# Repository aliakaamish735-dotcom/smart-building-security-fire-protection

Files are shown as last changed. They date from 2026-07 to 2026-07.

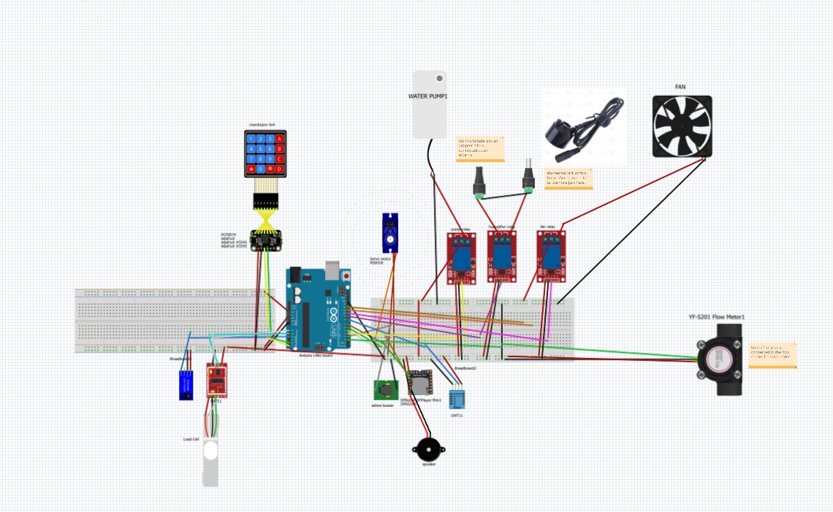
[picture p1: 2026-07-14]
docs/architecture_image.jpeg

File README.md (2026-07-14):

# Smart Building Security and Fire-Protection System

Welcome to the repository.

Smart Building Security and Fire-Protection System is an Arduino-based embedded sensing system integrating
optical, force, flow, temperature, and humidity sensors to provide intelligent entry security and automatic
fire detection and protection.

## Repository Contents

### 📁 `code/`

Contains the Arduino source code, firmware, diagnostics, and calibration
files.

### 📁 `data/`

Contains datasets, calibration files, CSV logs, and Excel workbooks.

### 📁 `docs/`

Contains the proposal, presentations, architecture diagrams, Fritzing
design, component documentation, and individual contributions.

### 📁 `report/`

Contains the final technical report.

### 📁 `video/`

Contains project demonstration and presentation video.

## Team Members

-   Ali Al Hadi Akaamish (6812)
-   Mustapha Hamdan (6947)
-   Nassim Amer (6939)
-   Makram Ghraizi (6723)

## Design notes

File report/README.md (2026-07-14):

# Security and Fire-Protection System

This folder contains the final technical report for the **Security and Fire-Protection System**, developed for the **Sensors & Instrumentation** course at the Lebanese University, Faculty of Engineering III.

## Main Report

- `security_and_fire_protection_systems_report.pdf`

The report presents the complete design, implementation, testing, data analysis, calibration framework, and evaluation of an Arduino-based smart sensing platform that combines building-entry security with automatic fire-protection functions.

## Project Team

1. **Ali Al Hadi Akaamish** — ID: 6812  
2. **Mustapha Hamdan** — ID: 6947  
3. **Nassim Amer** — ID: 6939  
4. **Makram Ghraizi** — ID: 6723  

**Instructor:** Dr. Mohamad Ahmad Aoude  
**Academic Year:** 2025–2026

## System Overview

The project is divided into two coordinated subsystems:

### Entry Security System

- TCRT5000 infrared optical sensor
- HX711 load-cell amplifier and load cell
- 4×4 keypad through a PCF8574 I²C expander
- SG90 servo-controlled door
- Security buzzer
- DFPlayer Mini voice guidance

A person is confirmed only when the optical sensor and entry-platform weight detection are both active. The user is then asked to enter a PIN. A correct PIN opens the door, while repeated incorrect attempts activate the security alarm.

### Fire-Protection System

- DHT11 temperature and humidity sensor
- YF-S201 water-flow sensor
- Mini water pump
- Ultrasonic humidifier
- Ventilation fan
- Warning LED
- Fire and blockage alarms
- DFPlayer Mini voice messages
- Three active-low relay modules

The fire-protection sequence monitors environmental conditions, detects high temperature, activates the pump, verifies water flow, operates the humidifier, controls ventilation, and records the system state.

## Sensor Modalities

The system integrates the five required sensor modalities:

- **Optical sensing:** TCRT5000
- **Force/weight sensing:** Load cell with HX711
- **Flow sensing:** YF-S201
- **Temperature sensing:** DHT11
- **Humidity sensing:** DHT11

## Report Contents

The report includes:

1. Introduction  
2. Problem Statement  
3. System Architecture  
4. Sensor Selection and Justification  
5. Hardware Design and Schematics  
6. Software Design and Firmware Architecture  
7. Calibration Procedures and Results  
8. Experimental Results and Data Analysis  
9. Measurement Uncertainty and Performance Analysis  
10. Engineering Constraints Discussion  
11. Conclusion and Future Work  
12. References  

It also includes appendices covering:

- Bill of Materials
- Verification and demonstration plan
- Proposal compliance matrix
- Calibration evidence and calculations
- Real-time acquisition and visualization
- Repository and submission checklist

## Data and Experimental Evidence

The report documents:

- 242 multi-sensor samples
- 113 system events
- Three acquisition sessions
- A longest continuous run of approximately 19.47 minutes
- Four recorded fire-response cycles
- Physical load-cell calibration trials
- Temperature, humidity, flow, event, and system-state visualizations
- Water-volume and timing calculations
- CSV-compatible timestamped data logging

## Hardware Documentation

The report contains the final Fritzing breadboard representation, interface mapping, power-domain explanation, relay connections, water-flow path, and complete Bill of Materials.

## Firmware Documentation

The firmware architecture includes:

- Continuous entry-security monitoring
- Five-second environmental acquisition and CSV logging
- Dual-sensor person confirmation
- Keypad PIN processing
- Servo-controlled door operation
- Fire-protection state machine
- Pump, humidifier, fan, LED, buzzer, and voice-message control
- Flow-based blockage detection
- Timestamped system-state records

## Recommended Repository Location

```text
report/
├── README.md
└── security_and_fire_protection_systems_report.pdf
```

## Purpose of This Document

This README provides a quick overview of the final report and helps reviewers understand the project scope, system structure, experimental work, and report organization before opening the complete PDF.

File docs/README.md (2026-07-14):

# Project Documentation

This folder contains the supporting documentation for the **Smart
Building Security and Fire-Protection System**.

## Files Included

### `Project_Team_Members.pdf`

Lists the project team members and their student IDs.

### `README_components.md`

Describes the hardware components, sensors, actuators, power supplies,
wiring accessories, and materials used in the project.

### `Smart_Laboratory_Security_Fire_Protection_Updated.pptx`

Final presentation used for the 10-minute technical presentation.

### `architecture_image.jpeg`

Illustrates the overall architecture of the system and the interaction
between the security and fire-protection subsystems.

### `questions&answers_ppt.pptx`

Contains the expected questions and prepared answers for the project
presentation and discussion.

### `sensors_architecture1.fzz`

Final Fritzing project containing the complete hardware wiring and
breadboard design.

### `sensors_project_proposal.pdf`

Original project proposal describing the objectives, requirements,
implementation plan, deliverables, and evaluation criteria.

## Purpose

These documents provide the technical background, hardware
documentation, presentation material, system architecture, and project
planning used throughout the design and implementation of the Smart
Building Security and Fire-Protection System.

## Folder Structure

``` text
docs/
├── README.md
├── Project_Team_Members.pdf
├── README_components.md
├── Smart_Laboratory_Security_Fire_Protection_Updated.pptx
├── architecture_image.jpeg
├── questions&answers_ppt.pptx
├── sensors_architecture1.fzz
└── sensors_project_proposal.pdf
```

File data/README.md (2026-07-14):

# Smart Building Security and Fire Protection — Project Data

This folder contains the complete dataset and analysis workbook for the **Smart Building Security and Fire Protection System**.

## Main Data File

- `whole_dataset_for_the_sensors_project(1).xlsx`

The Excel workbook is a standalone project database. It includes the original records, cleaned sensor data, event logs, calibration results, analysis-ready tables, charts, firmware constants, and a data dictionary.

## Important System Rule

The **HX711 load cell belongs only to the Entry Security System**.

It measures the weight applied to the entry platform and works together with the **TCRT5000 optical sensor** to confirm the presence of a person:

```text
Person detected = Optical detection AND Entry-platform weight detection
```

The load cell is **not used to measure the water tank** and is not interpreted as a fire-protection sensor.

## Workbook Contents

| Sheet | Description |
|---|---|
| `00_Cover` | Project description, fixed rules, cleaning decisions, and workbook summary |
| `01_Dashboard` | Main KPIs and charts for the report and presentation |
| `02_Parameters` | Firmware constants, thresholds, timings, and data-cleaning parameters |
| `03_Master_Data` | Organized master table containing sensor snapshots, system events, and calibration trials |
| `04_Clean_TimeSeries` | Clean, report-ready time-series sensor data |
| `05_Long_Observations` | Normalized sensor observations for calculations, filtering, and pivot tables |
| `06_Calibration` | Entry-platform load-cell calibration trials, equations, and results |
| `07_Event_Log` | Cleaned security, fire, and firmware event timeline |
| `08_Complete_Data_Archive` | Consolidated archive of all original project records |
| `09_Data_Dictionary` | Plain-English explanation of the important columns and variables |
| `10_Analysis_Data` | Analysis-ready records and calculated indicators |
| `11_Firmware_Calibration` | Calibration factors, equations, thresholds, and constants extracted from the firmware |
| `12_Nominal_References` | Reference values and comparison results |
| `13_Statistical_Calibration` | Simulated calibration points and before/after error calculations for modalities without complete measured calibration evidence |

## Dataset Summary

The workbook currently contains:

- **680** complete archive rows
- **370** master records
- **242** clean sensor snapshots
- **1,210** long-format sensor observations
- **113** cleaned system events
- **15** measured load-cell calibration trials

## Recorded Variables

The dataset includes values and events related to:

- TCRT5000 optical detection
- HX711 entry-platform weight
- DHT11 temperature and humidity
- YF-S201 water-flow rate
- Keypad activity and PIN-entry results
- Servo-controlled door operation
- Pump, humidifier, and fan states
- Fire-detection and suppression states
- Security alarms, wrong attempts, and detected errors

PIN values are masked in the clean analysis sheets.

## Main Firmware Parameters

| Parameter | Value |
|---|---:|
| Fire-temperature threshold | 28 °C |
| Flow blockage threshold | 0.05 L/min |
| Pump run duration | 55 s |
| Humidifier run duration | 10 s |
| Keypad inactivity timeout | 15 s |
| Maximum wrong attempts | 3 |
| Door-open duration | 5 s |
| TCRT5000 optical threshold | 500 ADC |
| Entry-platform weight threshold | 10 g |
| Flow calibration factor | 7.5 pulses/s per L/min |
| Sensor logging interval | 5 s |

These values are documented in the workbook and should be checked against the final physical calibration before the final demonstration.

## Data-Cleaning Decisions

The workbook preserves the original raw data while also providing clearly labelled cleaned and analysis-ready values.

- Negative load-cell readings remain preserved; the entry-weight analysis uses their positive magnitude.
- DHT11 values equal to `-1` are treated as failed sensor reads.
- Temperature values outside `0–60 °C` are excluded from clean measurements.
- Humidity values outside `0–100 %RH` are excluded from clean measurements.
- Very high historical flow values remain preserved; a clearly labelled analysis divisor is applied only where required.
- Legacy person-detection events are flagged when they do not follow the corrected optical-and-weight rule.

## How to Use the Workbook

1. Open `00_Cover` to review the system rules and workbook map.
2. Use `01_Dashboard` for presentation-ready KPIs and charts.
3. Use `03_Master_Data` for the organized complete dataset.
4. Use `04_Clean_TimeSeries` for sensor trends and report charts.
5. Use `07_Event_Log` to review security and fire-system actions.
6. Use `06_Calibration` and `11_Firmware_Calibration` when discussing sensor calibration.
7. Use `09_Data_Dictionary` to understand each important column.

## Calibration Note

Measured three-point calibration evidence is currently complete for the **entry-platform load cell**. Some additional calibration tables are based on nominal references or simulated data and are clearly identified as such inside the workbook. They should not be presented as physical measurements.

## File Organization

```text
data/
├── whole_dataset_for_the_sensors_project(1).xlsx
└── README.md
```

No additional `raw`, `processed`, or `calibration` folders are required because these categories are already organized into separate sheets inside the Excel workbook.

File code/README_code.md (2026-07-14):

# Project Source Code

This folder contains the complete source code for the **Smart Building Security and Fire-Protection System**.

## Code Structure

- `arduino_firmware/` — Main integrated Arduino firmware, calibration files, algorithm documentation, CSV logger, and experimental log.
- `arduino_firmware_modular/` — Modular implementation with separate configuration, security, fire-protection, relay, and sensor-driver files.
- `arduino_diagnostics/` — Diagnostic and calibration firmware used to test the connected hardware.
- `Code with no text output/` — Firmware version prepared for the final demonstration without additional Serial text messages.

## Main Features

- TCRT5000 optical person detection
- HX711 load-cell measurement
- DHT11 temperature and humidity monitoring
- YF-S201 water-flow measurement
- 4×4 keypad authentication through PCF8574
- SG90 servo-controlled door
- DFPlayer Mini voice guidance
- Pump, humidifier, and fan control through relay modules
- Timestamped CSV output
- Calibration constants and EEPROM support
- Modular Arduino C/C++ architecture
- Python serial-to-CSV logging utility

## External Libraries and Credits

The firmware uses the following external and Arduino-provided libraries. Their original authors, source repositories, and licenses are credited below.

### Third-Party Libraries

| Library | Author / Maintainer | Purpose | Source | License |
|---|---|---|---|---|
| DHT Sensor Library | Adafruit Industries | Reads DHT11 temperature and humidity values | https://github.com/adafruit/DHT-sensor-library | MIT License |
| HX711 Arduino Library | Bogdan Necula and contributors | Interfaces the HX711 load-cell amplifier | https://github.com/bogde/HX711 | MIT License |
| DFRobotDFPlayerMini | DFRobot | Controls the DFPlayer Mini audio module | https://github.com/DFRobot/DFRobotDFPlayerMini | MIT License |
| ArduinoJson | Benoit Blanchon and contributors | JSON formatting and data handling in diagnostic/modular code | https://github.com/bblanchon/ArduinoJson | MIT License |
| pySerial | Chris Liechti and contributors | Reads Arduino Serial data in the Python CSV logger | https://github.com/pyserial/pyserial | BSD-3-Clause License |

### Arduino-Provided Libraries

| Library | Provider | Purpose | Source | License |
|---|---|---|---|---|
| Servo | Arduino | Controls the SG90 servo motor | https://github.com/arduino-libraries/Servo | LGPL-2.1-or-later |
| Wire | Arduino | Provides I²C communication for the PCF8574 keypad expander | https://github.com/arduino/ArduinoCore-avr | LGPL-2.1-or-later |
| EEPROM | Arduino | Stores calibration constants in non-volatile memory | https://github.com/arduino/ArduinoCore-avr | LGPL-2.1-or-later |
| SoftwareSerial | Arduino | Provides software-based serial communication for the DFPlayer Mini | https://github.com/arduino/ArduinoCore-avr | LGPL-2.1-or-later |

## Project-Written Files

The subsystem algorithms, configuration files, calibration constants, sensor wrappers, relay logic, diagnostic routines, and project documentation included in this folder were developed specifically for this project.

## Programming Languages

- Arduino C/C++
- Python

## Usage

1. Install the required Arduino libraries through the Arduino IDE Library Manager.
2. Open the required `.ino` file in the Arduino IDE.
3. Select **Arduino Uno** and the correct serial port.
4. Compile and upload the firmware.
5. Use the Serial Monitor or `serial_csv_logger.py` to record CSV-formatted sensor data.

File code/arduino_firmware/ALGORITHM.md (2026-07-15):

# Firmware Algorithm — Smart Building Security and Fire Protection System

This document describes the **logic** of the firmware in plain pseudocode,
independent of Arduino syntax. It's meant to sit alongside `README.md`
(wiring/setup) as the "how it thinks" reference for the report's
Algorithm / Firmware Logic section.

The system is fully standalone (no WiFi/network) and runs two
independent subsystems every loop iteration: **Entry Security** and
**Fire Protection**. A third, smaller routine (**Ambient Humidity Fan
Control**) runs alongside Fire Protection but does not interact with it.

All numeric constants referenced below (in CAPS) live in
`CalibrationConstants.h` — nothing here is hard-coded in the driver files.

---

## 1. Main Loop

```
LOOP forever:
    POLL entry security (proximity + weight pad + keypad)   // every iteration, never skipped
    UPDATE fire-event buzzer timer                          // non-blocking, every iteration

    IF (time since last sensor read) >= SENSOR_POST_INTERVAL:
        RUN one fire-protection state-machine step
        LOG a CSV data row (temp, humidity, pad weight, flow, proximity, fire stage, wrong attempts)
```

Entry security is polled on **every single loop iteration**, regardless
of what the fire-protection state machine is doing. This guarantees a
fire event, a running pump, or a running humidifier never blocks
someone from unlocking the door.

---

## 2. Entry Security Algorithm

**Goal:** only prompt for a password when a person is *actually* at the
door — confirmed by two independent sensors — then check their PIN
locally and escalate to an alarm after repeated failures.

```
FUNCTION pollProximityAndKeypad():
    prox            ← read TCRT5000 IR proximity sensor (analog, 0-1023)
    proximityHit     ← prox < PHOTOCELL_THRESHOLD

    padWeight        ← read HX711 + load cell (grams)
    weightHit        ← padWeight > WEIGHT_DETECT_THRESHOLD_G

    personDetected   ← proximityHit AND weightHit      // BOTH sensors must agree

    IF personDetected AND (time since last trigger) > PROXIMITY_DEBOUNCE_MS:
        remember this trigger time
        PLAY "PLEASE ENTER PASSWORD"
        CALL waitForPinEntry()
```

```
FUNCTION waitForPinEntry():
    start a KEYPAD_TIMEOUT_MS countdown
    LOOP until timeout:
        key ← scan 4x4 keypad (via PCF8574 I2C expander)
        IF a key was pressed:
            reset the timeout countdown
            IF key == '#':          CALL submitPin(); RETURN
            ELSE IF key == '*':     clear the entry buffer
            ELSE IF key is 0-9:     append digit to entry buffer (max 8 digits)
            // 'A','B','C','D' reserved, currently ignored
    // loop exits silently on timeout (person walked away)
```

```
FUNCTION submitPin():
    IF entered PIN == stored DOOR_PIN:
        reset wrong-attempt counter
        silence any leftover alarm buzzer
        PLAY "ACCESS ACCEPTED"
        OPEN door servo, wait DOOR_OPEN_MS, CLOSE door servo

    ELSE:
        increment wrong-attempt counter
        IF wrong-attempt counter >= MAX_WRONG_ATTEMPTS:
            reset wrong-attempt counter
            PLAY "ACCESS DENIED, THIEF ATTEMPT"
            SOUND alarm buzzer (stays on — door stays locked)
        ELSE:
            PLAY "ACCESS DENIED"
```

**Key design points:**
- Proximity alone is not enough — the load-cell floor pad must also
  register a mass above `WEIGHT_DETECT_THRESHOLD_G` at the same time.
  This rejects false triggers from either sensor acting alone (someone
  walking past without stepping on the pad, or an object left on the
  pad with nobody at the door).
- `PROXIMITY_DEBOUNCE_MS` prevents the same person re-triggering the
  prompt repeatedly while still standing there.
- The wrong-PIN counter and thief-alarm decision are entirely local —
  there is no server, so the Arduino is the sole authority.

---

## 3. Fire Protection Algorithm

**Goal:** detect a fire via temperature, run a fixed water-pump cycle
(bailing out early on a pipe blockage), then run a fixed humidifier
cycle, then return to idle — all on fixed timers, independent of any
tank or humidity-level feedback.

State machine: `IDLE → FIRE_DETECTED → PUMPING → HUMIDIFYING → STABLE → IDLE`
(with a `BLOCKED` side-state if a blockage is detected mid-pump).

```
EVERY SENSOR_POST_INTERVAL:
    read temperature, humidity (DHT11)
    read flow rate (flow sensor pulse count → L/min, via FLOW_CALIBRATION_FACTOR)
    IF temp or humidity read failed: skip this step entirely

    RUN ambient-humidity fan control (independent — see section 4)

    SWITCH fireStage:

        CASE IDLE:
            IF temperature > FIRE_THRESHOLD_C:
                PLAY "HIGH TEMPERATURE DETECTED"
                TURN ON alarm LED
                START fire buzzer for a fixed FIRE_BUZZER_ON_MS (non-blocking,
                    auto-silences on its own timer every loop iteration)
                fireStage ← FIRE_DETECTED

        CASE FIRE_DETECTED:
            TURN ON pump
            START pump timer
            fireStage ← PUMPING

        CASE PUMPING:
            KEEP pump on
            IF flow rate <= FLOW_BLOCKAGE_LPM:
                TURN OFF pump
                PLAY "PIPE BLOCKAGE DETECTED"
                SOUND alarm buzzer
                fireStage ← BLOCKED                      // dead end, needs manual reset
            ELSE IF pump has run for PUMP_RUN_MS (55s):
                TURN OFF pump
                TURN ON humidifier
                START humidifier timer
                fireStage ← HUMIDIFYING

        CASE BLOCKED:
            KEEP pump off
            // stays here until the pipe is physically cleared and the
            // system is power-cycled/reset — no automatic recovery

        CASE HUMIDIFYING:
            KEEP humidifier on
            IF humidifier has run for HUMIDIFIER_RUN_MS (10s):
                TURN OFF humidifier
                PLAY "SYSTEM STABLE"
                TURN OFF alarm LED
                SILENCE buzzer (safety net)
                fireStage ← STABLE

        CASE STABLE:
            fireStage ← IDLE                             // ready to detect the next fire
```

**Key design points:**
- The pump (55s) and humidifier (10s) durations are both **fixed
  timers**, not conditions on flow, tank level, or humidity returning
  to normal — there is no tank in this system.
- The only early-exit path is a detected pipe blockage during pumping,
  which halts the whole sequence until a person physically clears it
  and resets the system.
- The 5-second fire buzzer is deliberately decoupled from the
  pump/humidifier timers — it always sounds for exactly 5s starting
  the instant fire is detected, checked every loop iteration so it
  never blocks keypad entry.

---

## 4. Ambient Humidity Fan Control (independent)

**Goal:** keep general ambient humidity in a comfortable range,
completely separate from the fire-suppression sequence above (it runs
every sensor cycle regardless of `fireStage`).

```
EVERY SENSOR_POST_INTERVAL (same cadence as fire protection):
    IF fan is OFF AND humidity > HUMIDITY_FAN_ON_PCT (60%):
        TURN ON fan
    ELSE IF fan is ON AND humidity <= NORMAL_HUMIDITY_PCT (70%):
        TURN OFF fan
```

Using two different thresholds (60% on / 70% off) is hysteresis — it
stops the fan from flickering on/off rapidly right at one boundary
value.

---

## 5. Constants Reference (all in `CalibrationConstants.h`)

| Constant | Meaning |
|---|---|
| `LOADCELL_SCALE_FACTOR` | HX711 raw-to-grams conversion (per-unit calibration) |
| `FLOW_CALIBRATION_FACTOR` | Flow sensor pulses/sec → L/min conversion |
| `FIRE_THRESHOLD_C` | Temperature that trips the fire sequence |
| `NORMAL_HUMIDITY_PCT` | Fan's turn-OFF humidity point (fan control only) |
| `HUMIDITY_FAN_ON_PCT` | Fan's turn-ON humidity point |
| `FLOW_BLOCKAGE_LPM` | Flow at/below this while pumping = blockage |
| `PUMP_RUN_MS` | Fixed pump run time (55,000 ms) |
| `HUMIDIFIER_RUN_MS` | Fixed humidifier run time (10,000 ms) |
| `FIRE_BUZZER_ON_MS` | Fixed fire-alert buzzer duration (5,000 ms) |
| `MAX_WRONG_ATTEMPTS` | Wrong PINs allowed before thief alarm |
| `PHOTOCELL_THRESHOLD` | TCRT5000 analog reading that counts as "person near door" |
| `WEIGHT_DETECT_THRESHOLD_G` | Load-cell floor-pad reading that counts as "someone standing on it" |
| `PROXIMITY_DEBOUNCE_MS` | Minimum time between password prompts |
| `KEYPAD_TIMEOUT_MS` | How long to wait for a full PIN entry |
| `DOOR_OPEN_MS` | How long the door stays unlocked |
| `SENSOR_POST_INTERVAL` | How often sensors are read + CSV-logged |
| `DOOR_PIN` | The accepted door PIN |

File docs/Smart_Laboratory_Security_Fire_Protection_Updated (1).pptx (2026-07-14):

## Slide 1

SENSORS PROJECT • UPDATED CONTROL LOGIC

ALI 1/3

Smart Laboratory Security
& Fire Protection

Dual-sensor entry • automatic fire response • timestamped evidence

IR + kg

ENTRY SECURITY

ARDUINO
CONTROL

°C + L/min

FIRE RESPONSE

TEAM

Ali • Makram • Nassim • Mustapha

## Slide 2

One controller supports two independent decision paths

ALI 2/3

ENTRY SECURITY

Infrared detection + entry weight

PIN request → door or sticky alarm

Both sensors must agree before authentication begins.

FIRE PROTECTION

Temperature + humidity + water flow

Pump → flow check → humidifier/fan

Fire decisions never read the load cell.

↓

↓

CORRECTION • The load cell belongs to the entry platform—not a tank and not the fire system.

SMART LABORATORY SYSTEM • 02

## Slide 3

Sampling matches how quickly each signal changes

ALI 3/3

SIGNAL

TCRT5000

SAMPLING

Every loop

WHY

Immediate optical presence

HX711 load cell

When data is ready

Entry-weight confirmation

Keypad

Continuously

15 s inactivity timeout

Flow sensor

Interrupt pulses

Flow calculated every 5 s

DHT11

Every 5 s

Temperature / humidity

Fire state + CSV

Every 5 s

Timestamped status record

The DHT11 changes slowly; a 5-second control/logging interval is stable, readable, and sufficient for the fire sequence.

SMART LABORATORY SYSTEM • 03

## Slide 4

Entry is confirmed only when both sensors agree

MAKRAM 1/3

TCRT5000
infrared = TRUE

AND

personDetected
= TRUE

THEN

REQUEST
PIN

HX711 load cell
weight ≥ threshold

Truth table

IR

0

WEIGHT

0

RESULT

No trigger

Sensor fusion rejects an infrared reflection without weight and a weight change without infrared presence.

1

0

0

1

No trigger

No trigger

1

1

Request PIN

SMART LABORATORY SYSTEM • 04

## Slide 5

Confirmed presence triggers the full security response

MAKRAM 2/3

1

2

3

4A

4B

CONFIRM

IR AND weight

REQUEST PIN

Voice prompt

VALIDATE

15 s • 8 digits

CORRECT

Door opens 5 s

3 WRONG

Sticky alarm

Automatic response: the servo opens only after a correct PIN; the thief buzzer remains active until a correct PIN clears it.

SMART LABORATORY SYSTEM • 05

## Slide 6

The fire controller advances through testable states

MAKRAM 3/3

> 27°C

pump ON

55 s + flow

≥ 70% RH

IDLE

FIRE
DETECTED

PUMPING

HUMIDIFYING

STABLE

next cycle → IDLE

≤ 0.05 L/min

BLOCKED
latched

The pump runs for the full 55 seconds unless flow indicates blockage. Temperature falling does not stop the pump early.

SMART LABORATORY SYSTEM • 06

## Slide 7

Timestamped CSV makes system behavior visible

NASSIM 1/3

SERIAL MONITOR • 9600 baud

timestamp,temp,humidity,entry_weight,IR,weight,person,flow,state,wrong

15000,25.4,54.0,68.2,1,1,1,0.00,IDLE,0

20000,28.1,55.2,0.0,0,0,0,0.12,PUMPING,0

Each row is machine-readable and immediately importable into Excel, MATLAB, or Python.

What the evidence proves

Real-time system status

Sensor fusion is visible

Fire states are traceable

At least 60 s can be logged

CSV every 5 seconds

SMART LABORATORY SYSTEM • 07

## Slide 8

Calibration turns raw readings into measurements

NASSIM 2/3

kg

CSV

±%

EEPROM

1 REFERENCE

Use at least three known weights or flow volumes.

2 RECORD

Save raw and reference values in the calibration CSV.

3 VALIDATE

Calculate factor, curve, and before/after error.

4 PERSIST

Store validated load-cell and flow factors in EEPROM.

TCRT5000 threshold is tuned for distance and lighting. If EEPROM is blank, dedicated constants provide safe defaults.

SMART LABORATORY SYSTEM • 08

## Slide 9

Protected power separates sensors from actuators

NASSIM 3/3

5 V LOGIC & SENSORS

Arduino Uno
TCRT5000 + HX711 load cell
DHT11 + flow-sensor signal
Keypad, DFPlayer, status LED

≤ 12 V DC ACTUATORS

Pump • humidifier • fan • servo

No direct mains connection

Fuse / diode / relay protection

Regulated supplies and common ground

Pin-to-pin wiring documented in Fritzing

RELAYS

→

In the final Fritzing schematic, the load cell is grouped with entry sensing—not with fire protection.

SMART LABORATORY SYSTEM • 09

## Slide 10

Fail-safe states and modular code improve reliability

MUSTAPHA 1/3

DHT failure skips the cycle; relays initialize OFF.

FAIL-SAFE

BLOCKED is latched; flow is checked while pumping.

ROBUST

Separate .ino modules, named thresholds, EEPROM calibration.

MAINTAINABLE

Pump, humidifier, fan, servo and buzzer run only when needed.

POWER-AWARE

Non-blocking timers keep monitoring active while alarms and actuators are operating.

SMART LABORATORY SYSTEM • 10

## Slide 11

Low-cost modules keep the prototype affordable

MUSTAPHA 2/3

COST CONSIDERATIONS

Arduino-class controller and common sensors

Replaceable modular components

Protection and calibration receive priority

No expensive cloud service is required

Trade-off: DHT11 and hobby modules reduce cost, but industrial deployment needs higher-grade sensors.

SCALABILITY ROADMAP

Dual entry + fire response

NOW

Smoke / gas sensing + SD log

NEXT

RTC, remote alerts, redundancy

LATER

Industrial sensors and enclosure

DEPLOY

SMART LABORATORY SYSTEM • 11

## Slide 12

Lecture concepts become a measurable safety workflow

MUSTAPHA 3/3

Signal conditioning

WHAT THE VIDEO DEMONSTRATES

continuous simulation
and timestamped logging

Dual-sensor entry → PIN response
Fire threshold → pump / flow / humidity
Serial Monitor → real-time CSV status

Calibration, thresholds, error

Sensor fusion

IR AND weight confirmation

60 s

Embedded timing

Interrupts + non-blocking timers

Control logic

State machine + automatic response

Data acquisition

Timestamped CSV + analysis

Two sensors confirm entry. Independent fire logic acts automatically. Every step is observable.

SMART LABORATORY SYSTEM • 12

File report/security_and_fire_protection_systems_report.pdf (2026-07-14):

SMART building | FINAL TECHNICAL REPORT

## LEBANESE UNIVERSITY

Faculty of Engineering III | Department of Computer and Communications Engineering

Sensors & Instrumentation

# Security and Fire-Protection System

## FINAL TECHNICAL REPORT

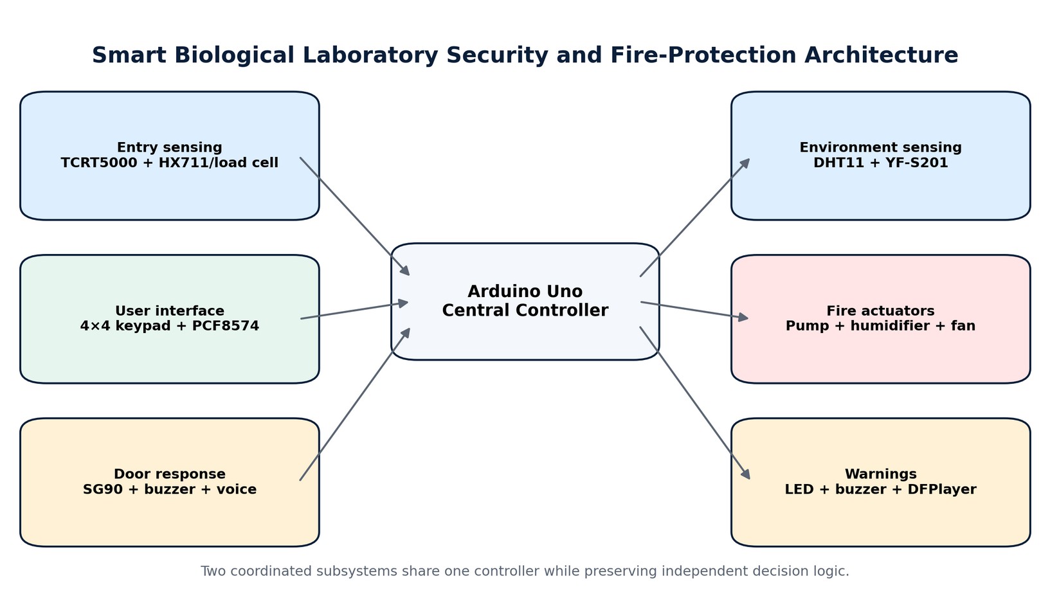
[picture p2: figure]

Prepared by | Project Team

1 Ali Al Hadi Akaamish - ID 6812

2 Mustapha Hamdan - ID 6947

3 Nassim Amer - ID 6939

4 Makram Ghraizi - ID 6723

Instructor: Dr. Mohamad Ahmad Aoude | Academic Year 2025-2026

# A Executive Summary

This project delivers an Arduino-based smart sensing platform for a building. The system combines controlled-entry security with automatic fire detection and environmental response. Five required sensing modalities are integrated: optical detection, applied force/weight, liquid flow, temperature, and humidity. The design acquires sensor data, performs threshold-based processing, controls electromechanical actuators, logs timestamped CSV records, and provides audible and visual feedback. The entry subsystem uses a TCRT5000 infrared sensor and an HX711-based load cell as a dual-confirmation gate. A PIN is requested only when optical presence and entry-platform weight are both confirmed. Correct credentials open a servo-controlled door for five seconds; three incorrect attempts activate a latched security alarm. The fire subsystem uses DHT11 temperature and humidity readings, a YF-S201 flow sensor, a pump, an ultrasonic humidifier, and a ventilation fan. The controller operates through a state machine with fire detection, pumping, blockage monitoring, humidification, and recovery states.

Experimental evidence at a glance

The organized test campaign contains 242 multi-sensor samples, 113 system events, three acquisition sessions, a longest continuous run of 1,168.41 s, four fire cycles (three complete), and 15 physical load-cell calibration trials. The main integrated run satisfies the minimum 60-second continuous-operation requirement by a wide margin.

Metric | Result | Interpretation
Samples | 242 | Multi-sensor snapshots
Longest continuous run | 1,168.41 s | Approximately 19.47 min
Median main-run interval | 5.018 s | Matches the 5 s firmware target
Event records | 113 | Security, fire and firmware events
Complete fire cycles | 3 of 4 | Fourth cycle was still pumping at end of capture
Grade-A samples | 211 (87.2%) | High overall dataset quality
Load-cell corrected MAPE | 98.60% | Scale factor must be recalibrated

Key engineering conclusion

The overall architecture and automatic responses are functional, but three issues require closure before final deployment: the load-cell scale factor is invalid, the fan threshold values are inconsistent between documentation and extracted constants, and the 24 V humidifier exceeds the course specification of 12 V maximum unless instructor approval and electrical isolation are formally documented.

# B Contents and Report Map

Section | Title
1 | Introduction
2 | Problem Statement
3 | System Architecture
4 | Sensor Selection and Justification
5 | Hardware Design and Schematics
6 | Software Design and Firmware Architecture
7 | Calibration Procedures and Results
8 | Experimental Results and Data Analysis
9 | Measurement Uncertainty and Error Analysis
10 | Engineering Constraints Discussion
11 | Conclusion and Future Work
12 | References
Appendices A-F | BOM, verification plan, compliance, calibration evidence, visualization, and closure package
D | Complete Calibration Evidence Pack
E | Real-Time Acquisition and Visualization Evidence
F | Proposal Closure, Repository and Submission Checklist

## Symbols and abbreviations

Term | Meaning | Term | Meaning
ADC | Analog-to-digital count | Q | Flow rate, L/min
f | Pulse frequency, pulses/s | RH | Relative humidity, %
MAPE | Mean absolute percentage error | CSV | Comma-separated values
I2C | Inter-integrated circuit bus | GPIO | General-purpose I/O
I/O | Inputs, outputs and relay contacts

1

# Introduction

Project purpose, context and contribution

The building contains controlled-access zones, sensitive equipment, electrical loads, chemical materials, and environmental risks. A conventional installation often treats access control, fire detection, ventilation, alarms, and data logging as separate systems. The proposed prototype demonstrates how heterogeneous sensors can be integrated into a unified embedded platform without mixing the decision logic of the individual subsystems.
The project is implemented around an Arduino Uno and divides the application into two coordinated but independent subsystems. The entry-security subsystem protects the laboratory door. The fire-protection subsystem monitors environmental conditions and automatically activates suppression and ventilation hardware. A shared controller simplifies prototyping, while modular firmware and clear subsystem boundaries preserve maintainability.

## 1.1 Project objectives

- Integrate optical, force, flow, temperature and humidity sensing in one Arduino-based system.
- Acquire and log timestamped multi-sensor data with a nominal five-second reporting interval.
- Reduce false entry triggers by requiring simultaneous optical and load-cell confirmation.
- Detect abnormal temperature and control a pump, humidifier, fan, alarms and warning indicators automatically.
- Implement calibration, error analysis, data visualization, modular firmware and a reproducible GitHub structure.
- Demonstrate continuous operation for more than 60 seconds and explain all design decisions during the live demonstration.

## 1.2 Main contribution

The principal contribution is a compact laboratory monitor that links sensing, decision making, actuation, audio guidance, and data engineering. The load cell is deliberately assigned only to the entry platform; it is not used as a water-tank sensor. This corrected allocation gives each required sensor modality a distinct and meaningful engineering role.
2

# Problem Statement

Why a dual-purpose laboratory monitor is needed

A laboratory entry system based on only one proximity sensor may trigger because of reflections, nearby objects, or ambient-light changes. Similarly, a fire alarm that only reports high temperature without checking water delivery cannot determine whether the suppression path is blocked. The problem is therefore not simply to read sensors, but to combine them into dependable decisions and automatic responses.

## 2.1 Functional problem

Hazard / need | Conventional weakness | Implemented response
Unauthorized access | Single-sensor triggers and repeated PIN attempts | Optical AND weight confirmation, PIN timeout, sticky thief alarm
Fire or overheating | Alarm without active response | Temperature threshold, warning LED, buzzer, pump and humidifier sequence
Blocked water path | Pump may run without useful delivery | Flow threshold and latched blockage state
Excess humidity | Humidity may remain high after suppression | Automatic ventilation fan control
Poor traceability | Manual observations are incomplete | Timestamped CSV logging and event records

## 2.2 Design specifications

Requirement | Target
Required modalities | Optical, force, flow, temperature, humidity

Requirement | Target
Entry confirmation | TCRT5000 detection AND entry weight >= 10 g
PIN inactivity timeout | 15 s
Maximum wrong attempts | 3
Door-open interval | 5 s
Fire threshold | 28 °C target constant
Flow blockage threshold | 0.05 L/min
Pump duration | 55 s nominal
Humidifier interval | 10 s measured timer window / RH target check
Logging interval | 5 s
Continuous demonstration | At least 60 s

3

# System Architecture

Subsystem boundaries, data flow and control

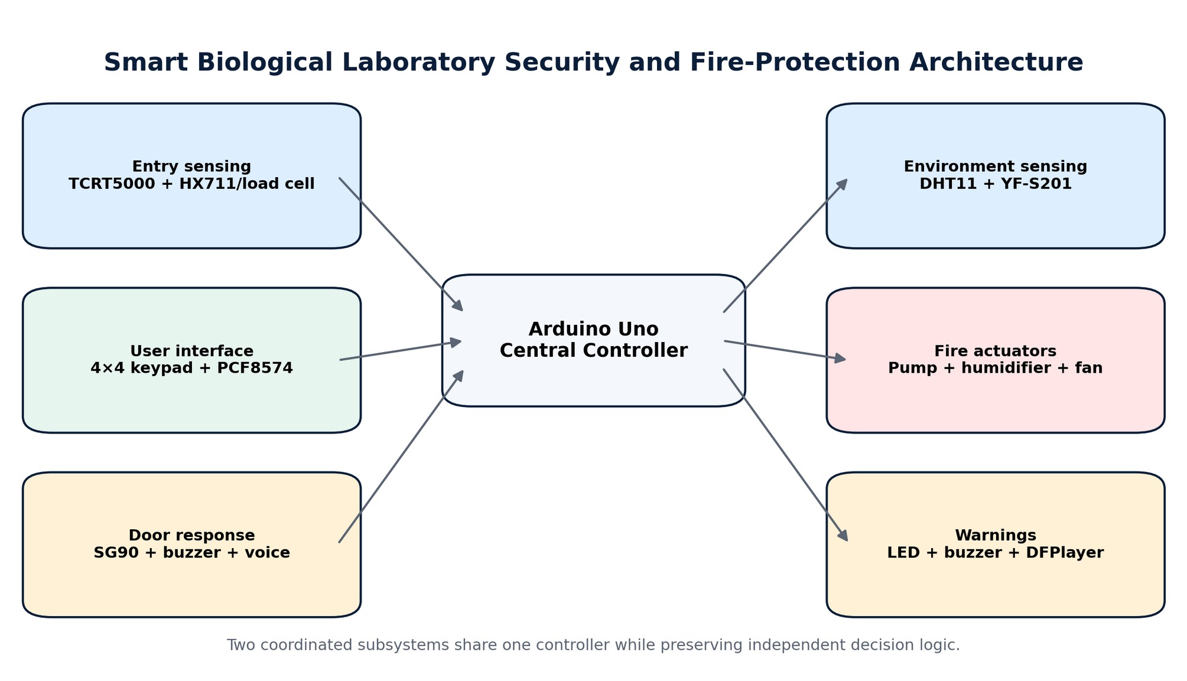
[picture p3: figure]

Figure 3.1 - Functional block architecture

The Arduino Uno coordinates all sensing and actuation. Entry-security tasks are polled continuously for rapid response. Fire-protection processing and CSV output execute every five seconds. The security and fire state variables remain separate: entry weight cannot initiate, stop, or modify the fire sequence.

## 3.1 Entry-security data path

opticalDetected = (TCRT5000 ADC < 500) weightDetected = (entry-platform weight >= 10 g) personDetected = opticalDetected AND weightDetected

When personDetected becomes true and the debounce interval has elapsed, the DFPlayer prompts the user for a PIN. The keypad is scanned through the PCF8574 expander. A correct PIN resets the alarm and rotates the SG90 servo to open the door. An incorrect PIN increments the attempt counter; after three failures the buzzer remains active until a correct PIN is entered.

## 3.2 Fire-protection data path

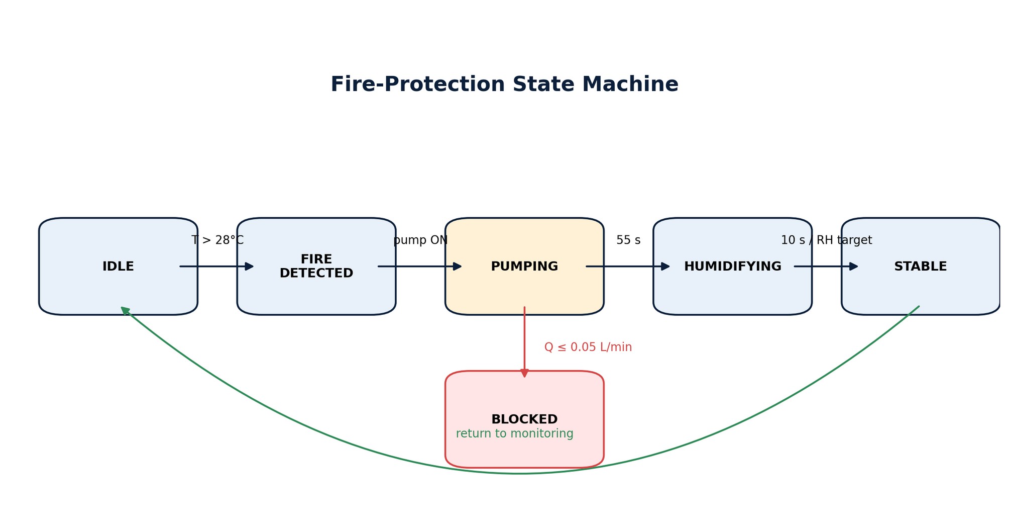
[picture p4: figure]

Figure 3.2 - Fire-protection state machine

The DHT11 provides temperature and humidity, while the YF-S201 produces flow pulses. High temperature moves the controller from IDLE to FIRE_DETECTED, activates warning outputs, and starts the pump. During pumping, the measured flow is compared with the 0.05 L/min blockage threshold. After the pump interval, the humidifier is activated and the system returns to stable monitoring after the recovery condition.

## 3.3 Data acquisition and visualization

The serial stream contains timestamp, temperature, humidity, entry weight, optical state, weight state, combined person state, water flow, fire stage, and wrong-attempt count. This format can be imported directly into Excel or a live serial plotter. The main experimental session used a median interval of 5.018 s, closely matching the firmware target of 5 s.

4

# Sensor Selection and Justification

Why each modality is necessary

Role | Component | Measured / controlled quantity | Interface | Justification
Optical | TCRT5000 IR module | Object/person presence | Analog A2 | Low-cost short-range reflective detection; threshold can be tuned for the installed distance.
Force | Load cell + HX711 | Applied entry-platform weight | Digital serial interface | Adds physical confirmation and rejects optical-only false triggers.
Flow | YF-S201 | Water flow, L/min | Digital interrupt D2 | Pulse output supports blockage detection and delivered-volume estimation.
Temperature | DHT11 | Ambient temperature, °C | Digital D8 | Direct input to abnormal-temperature detection.
Humidity | DHT11 | Relative humidity, %RH | Digital D8 | Controls recovery and ventilation after suppression.
User input | 4x4 keypad + PCF8574 | PIN digits | I2C, address 0x20 | Reduces Arduino pin consumption and supports clear access control.
Door actuator | SG90 servo | Door angle | PWM control | Provides repeatable open/close motion.
Audio | DFPlayer Mini + speaker | Voice prompts and warnings | Serial control | Improves usability and communicates system state without a display.

## 4.1 Distinct role of the load cell

Architecture rule

The load cell is an entry-security sensor only. It measures applied weight on the entry platform and must never be described as a tank-level or fire-protection sensor.

## 4.2 Signal-conditioning considerations

- The HX711 provides amplification and high-resolution conversion for the load cell; tare is executed with the platform empty.
- The TCRT5000 threshold is applied to a raw ADC reading and must be tuned under the laboratory lighting and mounting distance.
- The YF-S201 pulse line is connected to an interrupt-capable input; pulse frequency is converted to L/min.
- Relay modules isolate Arduino logic from the pump, humidifier and fan load currents. Active-low logic requires a defined OFF state during startup.
- The warning LED requires a current-limiting resistor, and all modules share an appropriate reference ground on the low-voltage control side.

5

# Hardware Design and Schematics

Prototype wiring, power domains and physical integration

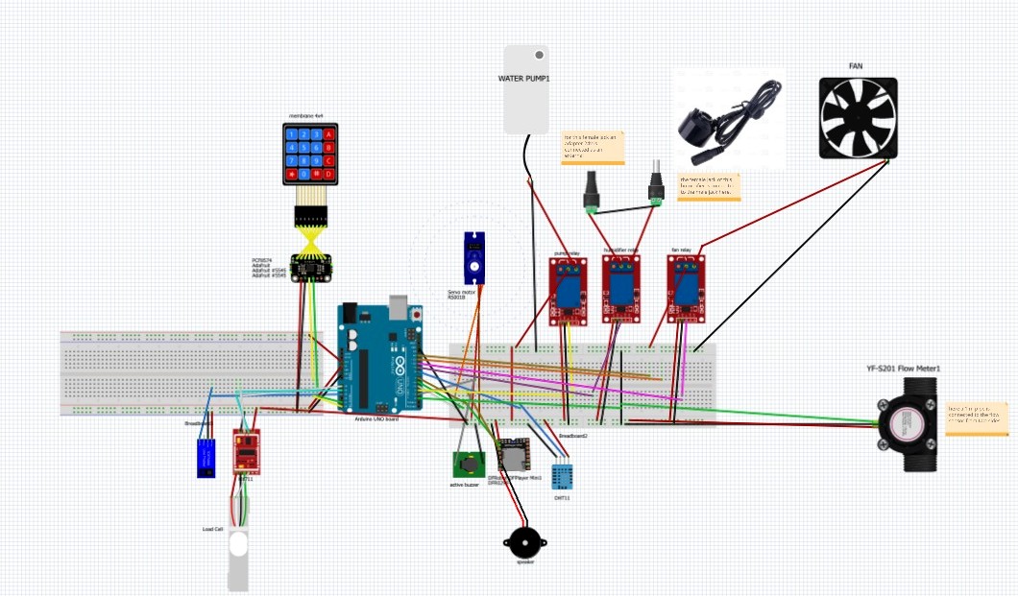
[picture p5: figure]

Figure 5.1 - Final Fritzing breadboard representation of the integrated prototype

The breadboard layout places the Arduino Uno at the center, with the entry hardware on the left and environmental actuators on the right. Three active-low relay modules switch the pump, humidifier and fan. The keypad is routed through the PCF8574 expander, and the audio subsystem is positioned near the DHT11 and controller. Male and female barrel connectors represent the external humidifier power connection.

## 5.1 Known interface map

Device | Verified interface | Notes
TCRT5000 | A2 | Raw ADC compared with the optical threshold
DHT11 | D8 | Temperature and humidity, read every 5 s
YF-S201 | D2 interrupt | Pulse counting for flow conversion
PCF8574 keypad expander | I2C address 0x20 | Rows and columns connected through the expander
SG90 servo | PWM-capable digital output | 0° closed, 180° open in corrected algorithm
Pump / humidifier / fan relays | Active-low digital outputs | COM/NO contacts switch the load supply
DFPlayer Mini | Serial interface | Voice prompts and warnings

## 5.2 Power and protection

- Arduino and logic modules operate from the regulated low-voltage control supply.
- The pump, fan and humidifier are powered through relay contacts rather than Arduino GPIO pins.
- The 24 V humidifier adapter is connected only on the isolated relay-load side; the Arduino must never receive 24 V.
- Barrel-jack polarity is center-positive unless the actual adapter label specifies otherwise.

- Inductive loads should include appropriate flyback protection where it is not already provided by the relay module or load driver.
- Water tubing and the electronics should be physically separated to reduce leak risk.
Course-voltage compliance

The course specification states a maximum operating voltage of 12 V DC. The current 24 V humidifier therefore requires formal instructor approval or replacement by a 12 V unit. Electrical isolation alone does not remove this specification conflict.

## 5.3 Water path

The recommended hydraulic path is: water container -> mini pump -> YF-S201 flow sensor -> humidifier reservoir or discharge outlet. Six-millimeter flexible tubing, secure fittings and leak testing are required. The flow sensor should be oriented according to its arrow and kept full of water during measurement to reduce air-bubble error.

6

# Software Design and Firmware Architecture

Modular control, timing and fault handling

The firmware is organized into a main Arduino file and subsystem modules for entry security and fire protection. Startup configures all pins, initializes peripherals, tares the load cell, sets active-low relays OFF, closes the servo door and prints the CSV header.

## 6.1 Main scheduler

Task | Execution rate | Reason
Optical and load-cell polling | Continuous | Fast reaction at the door
Keypad processing | During active PIN session | Immediate feedback and timeout restart
Non-blocking buzzer update | Continuous | Alarm timing without stopping other tasks
DHT11 and flow processing | Every 5 s | Sensor limitations and manageable log rate
Fire-state update | Every 5 s | Coordinated state progression
CSV record output | Every 5 s | Analysis-ready time series

## 6.2 Entry algorithm

1. Read the TCRT5000 ADC value and the most recent HX711 weight.
2. Calculate opticalDetected and weightDetected using the configured thresholds.
3. Require the logical AND of both conditions before requesting a PIN.
4. Accept numeric keys, use # to submit, * to clear, and ignore A-D.
5. Open the door for five seconds after a correct PIN.
6. After three incorrect attempts, latch the security alarm until a correct PIN is entered.

## 6.3 Fire algorithm

1. Read temperature, humidity and accumulated flow pulses.
2. When temperature exceeds the fire threshold, activate the warning outputs and enter FIRE_DETECTED.
3. Start the pump and monitor flow. Enter BLOCKED when flow is at or below 0.05 L/min.
4. After the nominal 55-second pump interval, stop the pump and start humidification.
5. Stop humidification at the selected recovery criterion and return to stable monitoring.
6. Control the fan with separated ON and OFF thresholds to provide hysteresis.

## 6.4 Important firmware corrections

Issue observed | Engineering effect | Required correction
DHT failure skips the entire fire-state step | Pump completion may be delayed beyond 55 s | Check pump and alarm timers independently of DHT validity
Fan thresholds differ between algorithm text and extracted constants | Risk of chattering or contradictory behavior | Adopt one hysteresis pair, e.g. ON >= 80%RH and OFF <= 70%RH
Humidifier logic appears both timer-based and humidity-based | Documentation and test behavior may disagree | Use RH target with a 10 s maximum safety timeout
Load-cell factor 420 is an initial guess | Entry weight is severely inaccurate | Perform new raw-count calibration and store the final factor in a constants file or EEPROM

7

# Calibration Procedures and Results

Three-point methods, equations and measured limitations

## 7.1 Calibration equations

error = measured value - reference value percentage error = 100 x error / reference MAPE = mean(|percentage error|) linear correction: y = m x + b

## 7.2 Physical load-cell calibration

Fifteen trials were recorded at three known reference weights: 500 g, 1,000 g and 2,000 g, with five repetitions per point. Signed readings were converted to positive magnitude because the mechanical mounting reversed the sign. The average measurements were 17.136 g, 6.199 g and 2.761 g respectively.

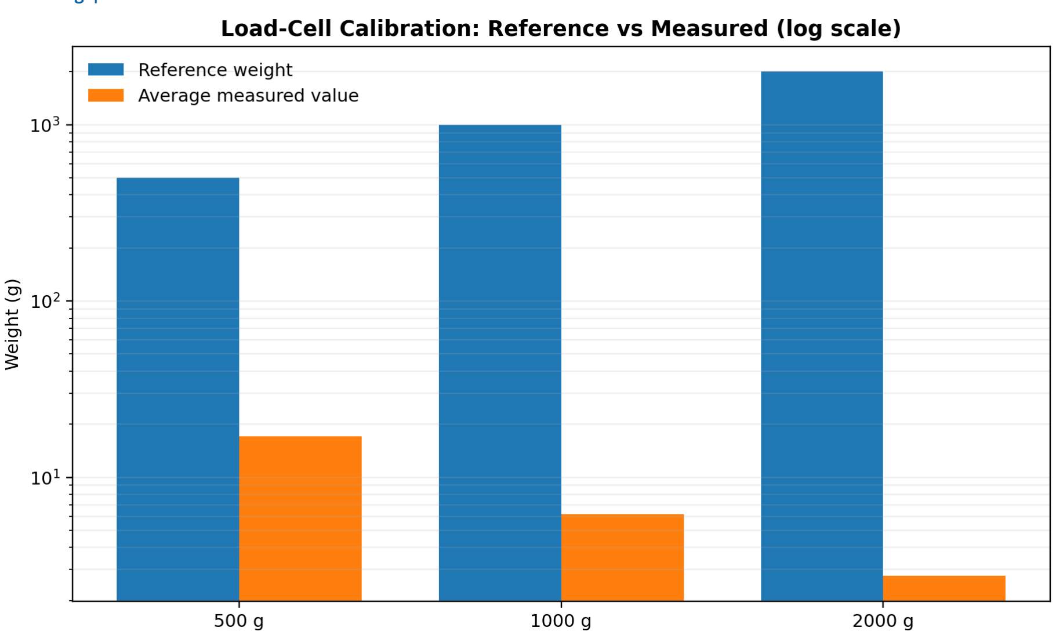
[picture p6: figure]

Figure 7.1 - Physical load-cell calibration results

Reference | Trials | Average measured | Average absolute error | MAPE
500 g | 5 | 17.136 g | 482.864 g | 96.573%
1,000 g | 5 | 6.199 g | 993.801 g | 99.380%
2,000 g | 5 | 2.761 g | 1,997.239 g | 99.862%
Overall | 15 | - | - | 98.605%

Calibration decision

The current scale factor cannot be accepted. The measured response is not proportional to the applied reference weight, so changing only the 10 g presence threshold would not solve the problem. Raw HX711 counts, tare offset and mounting polarity must be re-recorded before the final demonstration.

## 7.3 Required load-cell recalibration procedure

1. Unload the entry platform and execute tare.
2. Record the average raw HX711 count for at least 0 g, 500 g, 1,000 g and 2,000 g.
3. Fit reference weight against net raw count using linear regression.
4. Store the resulting scale factor and offset in the dedicated constants file or EEPROM.
5. Repeat each point at least five times and calculate bias, standard deviation and MAPE.
6. Choose the entry threshold only after the calibrated noise floor and intended platform load are known.

## 7.4 Statistical three-point validation for the remaining sensors

The environmental and optical datasets were also evaluated through three-point statistical correction. These points demonstrate the calculation method and sensitivity of a linear correction, but they are not a substitute for physical references such as a thermometer, hygrometer, controlled target distance or measured water volume.

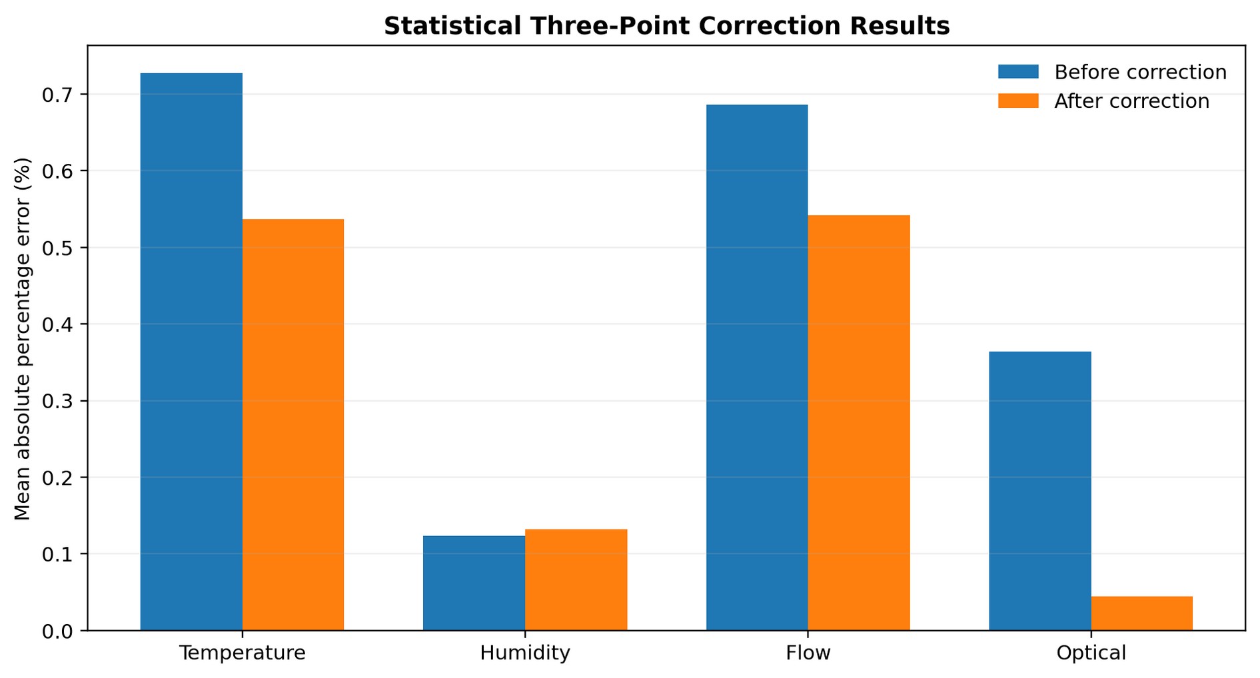
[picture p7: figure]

Figure 7.2 - Before/after error for statistical three-point correction

Sensor | Correction equation | Before MAE % | After MAE % | Interpretation
DHT11 temperature | y = 0.8242x + 4.7802 | 0.727 | 0.537 | Small statistical improvement
DHT11 humidity | y = 1.0021x - 0.1309 | 0.123 | 0.132 | No meaningful improvement
YF-S201 flow | y = 1.0226x - 0.0210 | 0.686 | 0.542 | Small improvement
TCRT5000 optical | y = 0.9674x + 29.5607 | 0.364 | 0.045 | Strong fit to selected statistical points

## 7.5 Physical three-point calibration still required

Sensor | Recommended physical references
DHT11 temperature | Three stable temperatures measured with a reference thermometer
DHT11 humidity | Three humidity conditions measured with a reference hygrometer
YF-S201 | Three known collected volumes divided by stopwatch time
TCRT5000 | Three controlled distances/targets under fixed lighting

8

# Experimental Results and Data Analysis

Time series, events, automatic responses and calculated performance

## 8.1 Test campaign summary

Session | Samples | Start | End | Duration | Median interval
Session 1 | 11 | 5.207 s | 153.318 s | 148.111 s | 15.536 s
Session 2 | 9 | 5.161 s | 132.052 s | 126.891 s | 15.454 s
Main integrated run | 222 | 5.107 s | 1,173.517 s | 1,168.410 s | 5.018 s

The main run lasted approximately 19.47 minutes and therefore exceeded the required 60-second continuous demonstration by a factor of about 19.5. The median sampling interval of 5.018 s confirms that the primary logging schedule operated as intended.

## 8.2 Environmental measurements

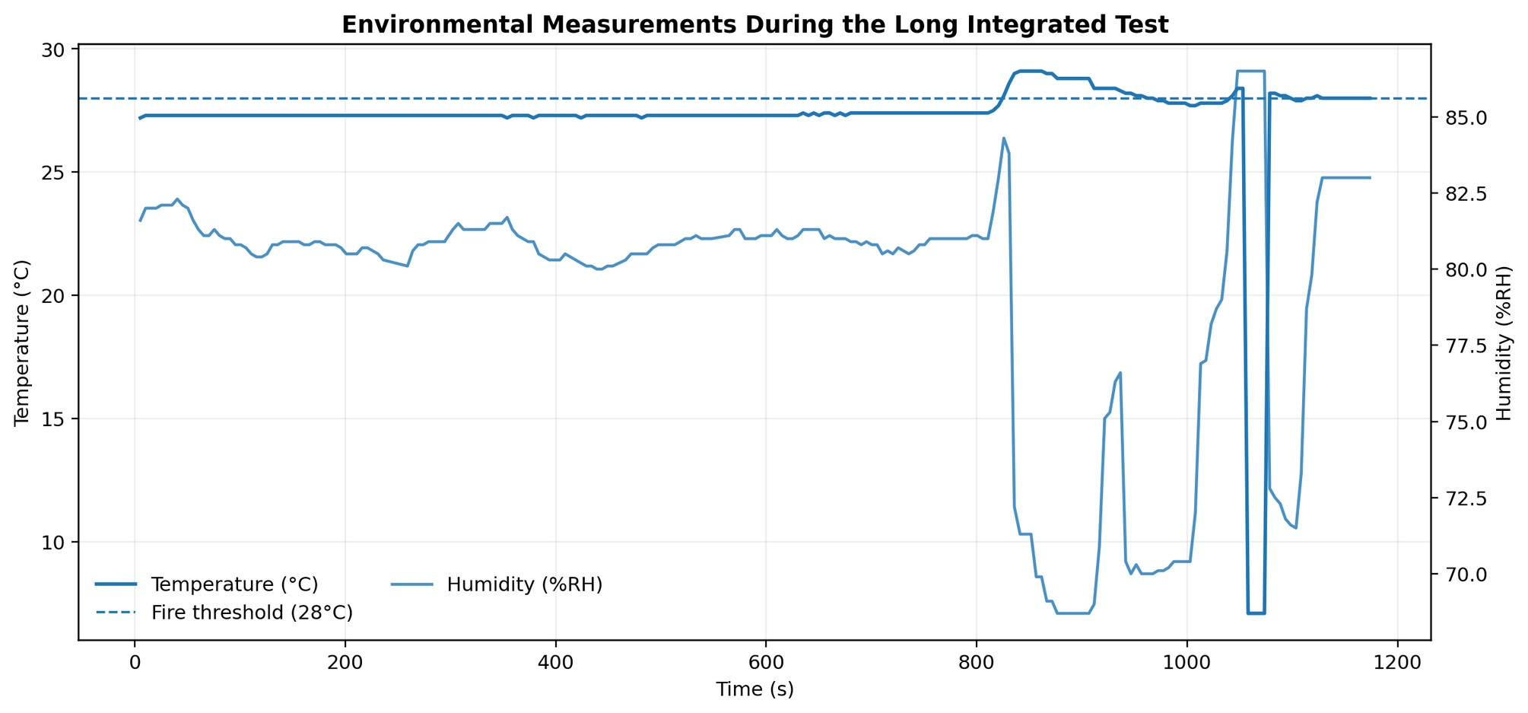
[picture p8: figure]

Figure 8.1 - Temperature and humidity during the main integrated run

Variable | Count | Minimum | Mean | Median | Maximum | Std. deviation
Temperature (°C) | 242 | 7.10 | 26.82 | 27.30 | 29.10 | 3.01
Humidity (%RH) | 242 | 68.70 | 78.64 | 80.80 | 86.50 | 4.79
Flow (L/min) | 242 | 0.00 | 0.276 | 0.00 | 4.963 | 0.671

## 8.3 Water-flow response

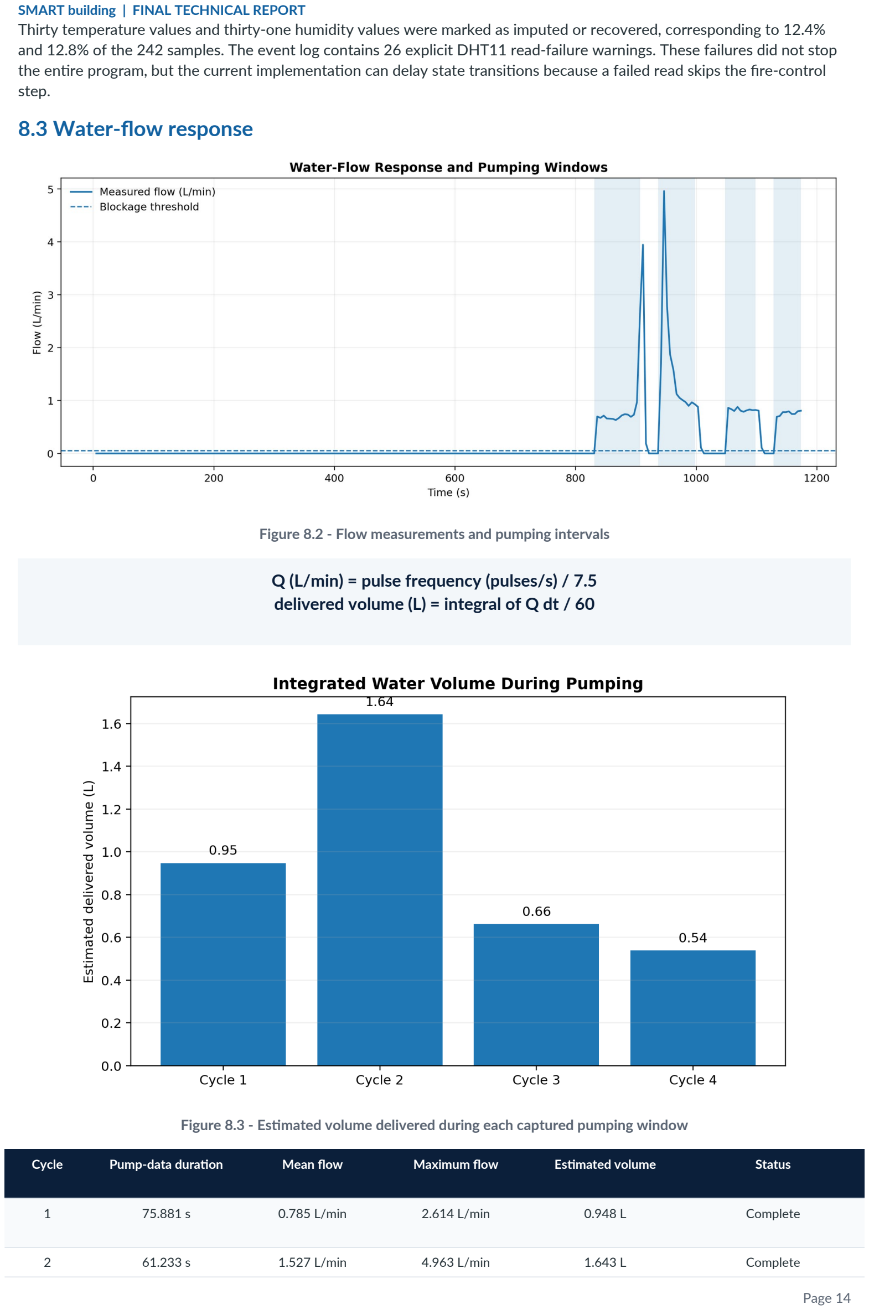
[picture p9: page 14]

Thirty temperature values and thirty-one humidity values were marked as imputed or recovered, corresponding to 12.4% and 12.8% of the 242 samples. The event log contains 26 explicit DHT11 read-failure warnings. These failures did not stop the entire program, but the current implementation can delay state transitions because a failed read skips the fire-control step.

Figure 8.2 - Flow measurements and pumping intervals

Q (L/min) = pulse frequency (pulses/s) / 7.5 delivered volume (L) = integral of Q dt / 60

Figure 8.3 - Estimated volume delivered during each captured pumping window

Cycle | Pump-data duration | Mean flow | Maximum flow | Estimated volume | Status
1 | 75.881 s | 0.785 L/min | 2.614 L/min | 0.948 L | Complete
2 | 61.233 s | 1.527 L/min | 4.963 L/min | 1.643 L | Complete

Cycle | Pump-data duration | Mean flow | Maximum flow | Estimated volume | Status
3 | 50.515 s | 0.751 L/min | 0.881 L/min | 0.661 L | Complete
4 | 45.043 s | 0.686 L/min | 0.807 L/min | 0.538 L | Capture ended before completion

The integrated volumes are dataset-based estimates, not volumetric calibration standards. Each pumping cycle contained at least one sample at or below the 0.05 L/min blockage threshold, yet the recorded cycles generally continued. The final firmware should apply a short persistence window or startup grace period so that a single zero-flow sample at pump activation does not falsely latch BLOCKED.

## 8.4 Fire-cycle timing

Cycle | Fire detected | Pump complete | Observed interval | Humidifier interval
1 | 820.720 s | 906.633 s | 85.913 s | 9.968 s
2 | 926.602 s | 997.836 s | 71.234 s | 9.969 s
3 | 1,037.896 s | 1,098.443 s | 60.547 s | 10.001 s
4 | 1,118.443 s | Not captured | Incomplete | Incomplete

The three completed humidifier intervals closely match ten seconds. The time from fire detection to pump completion exceeded 55 seconds, especially during cycle 1, because repeated DHT11 failures prevented the state update from checking the pump timer. This result directly supports moving timing checks outside the DHT-validity branch.

## 8.5 Security results

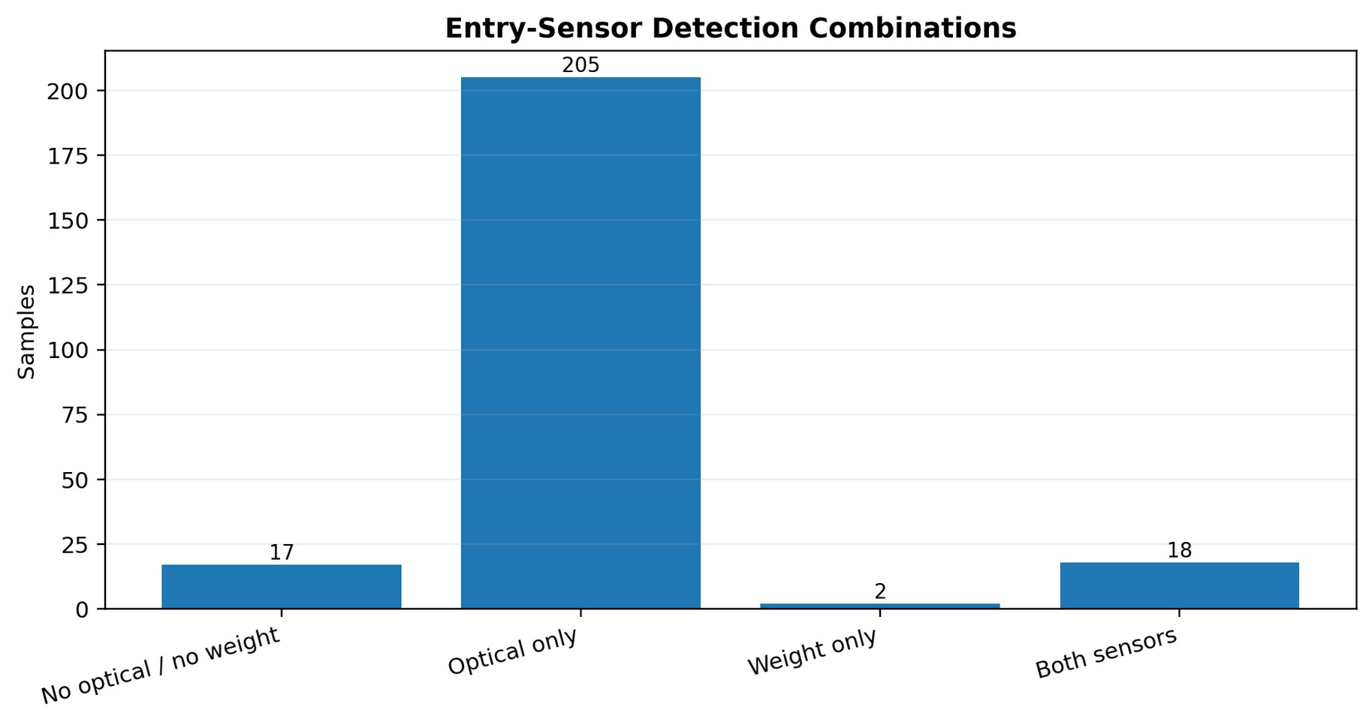
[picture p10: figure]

Figure 8.4 - Optical and load-cell detection combinations

At sample level, 18 records simultaneously satisfied optical and weight thresholds. Seven additional records were tagged as logged dual-sensor events even though the nearest sensor snapshot did not contain weight above 10 g; these are retained as event-linked evidence rather than treated as threshold-valid samples. The event log also contains 19 legacy optical-only proximity triggers, demonstrating why the corrected AND rule is necessary.

Security event | Count
Legacy proximity trigger | 19
PIN entry started | 18
Dual-sensor person detected | 8
PIN submitted | 8
Password correct | 1
Door opened | 1
Door closed | 1

## 8.6 Event and data-quality distribution

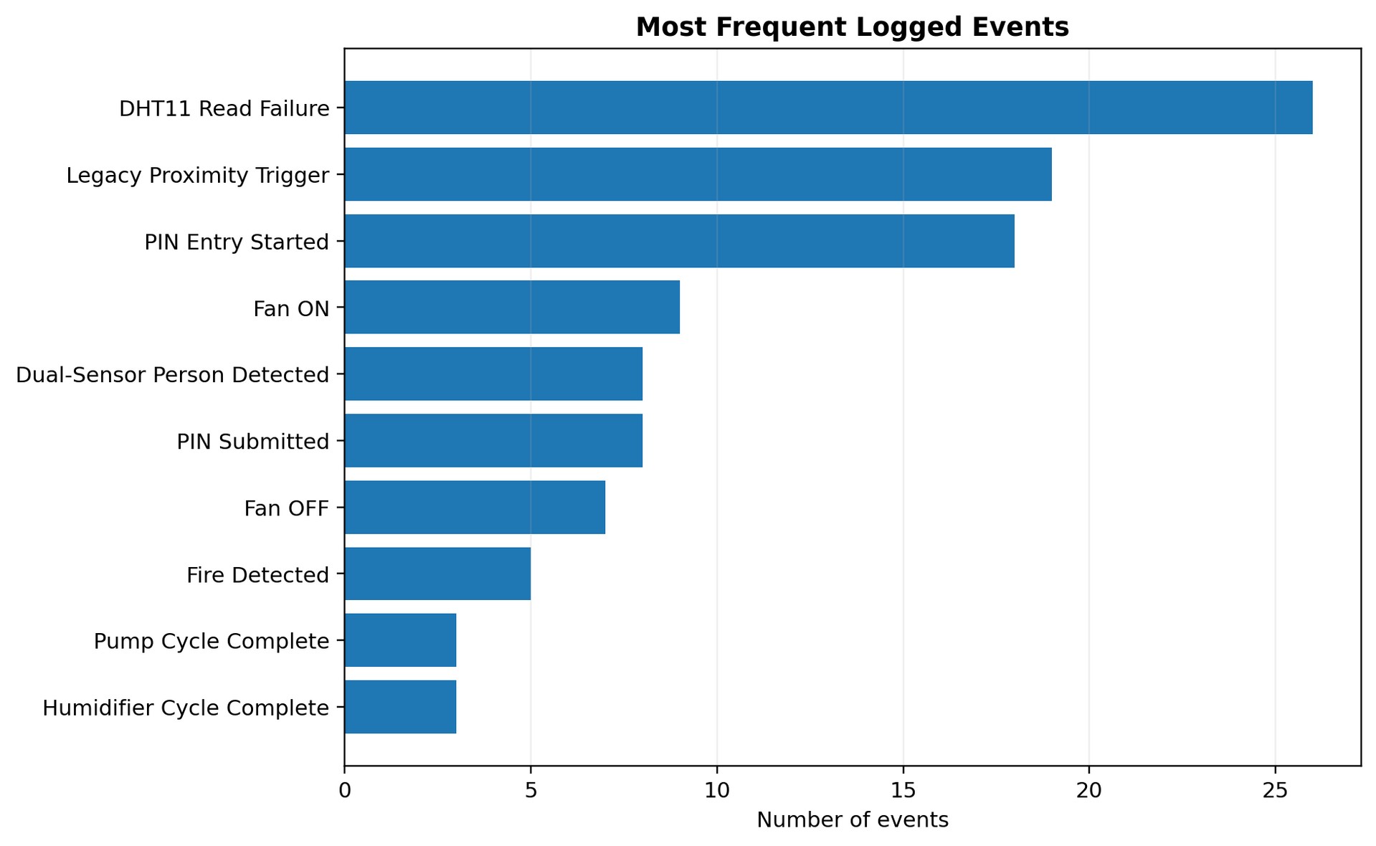
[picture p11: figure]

Figure 8.5 - Most frequent system events

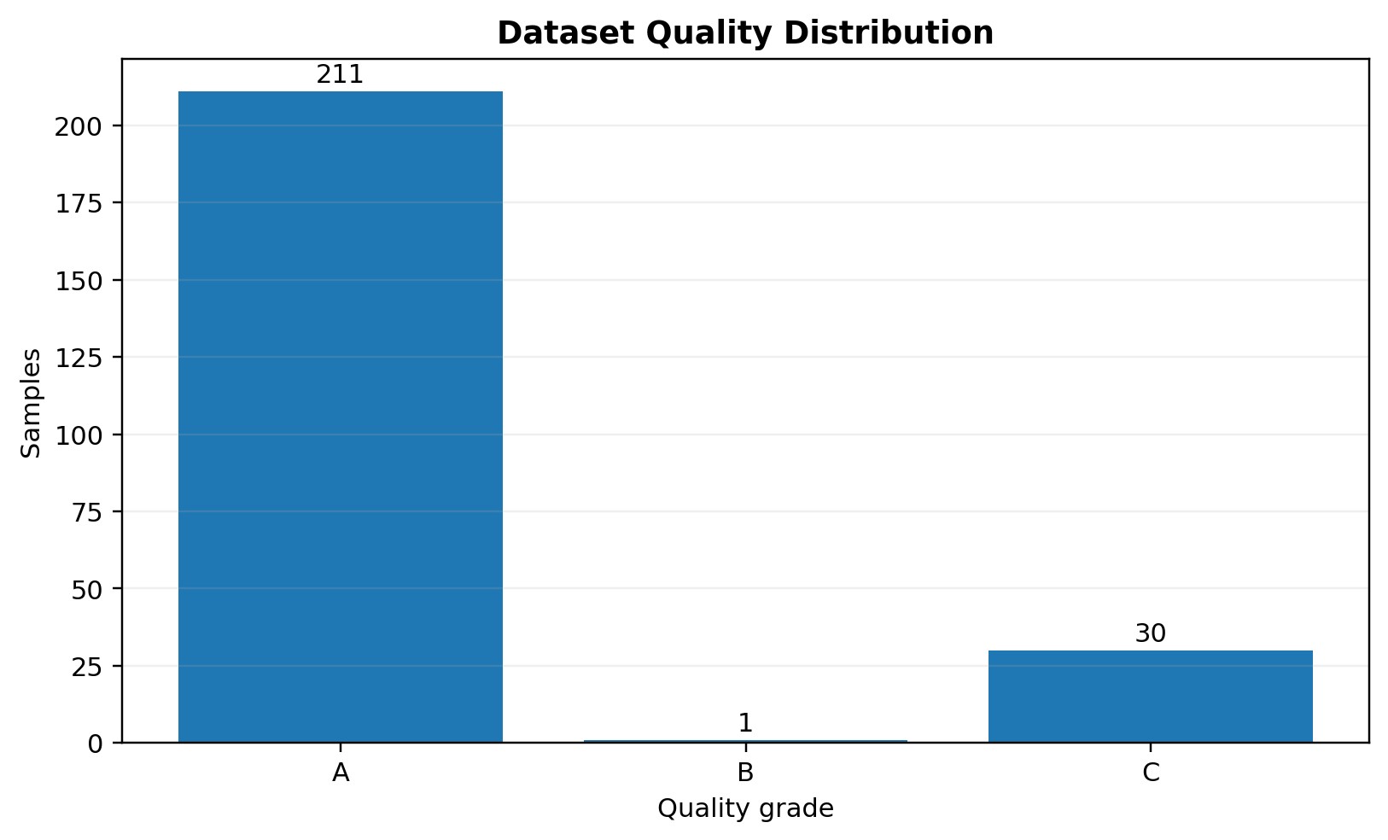
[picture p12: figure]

Figure 8.6 - Dataset quality grades

Quality grade | Samples | Percentage
A | 211 | 87.2%
B | 1 | 0.4%
C | 30 | 12.4%

9

# Measurement Uncertainty and Error Analysis

Accuracy, repeatability, noise and improvement strategy

## 9.1 Main uncertainty sources

Measurement | Dominant uncertainty sources | Observed evidence | Improvement
Entry weight | Mechanical mounting, tare drift, incorrect scale factor, sign inversion | 98.6% MAPE; non-monotonic averages | Rebuild mount; record raw counts; multi-point regression
Optical ADC | Target reflectivity, angle, distance, ambient IR | Wide range 48-865 ADC | Fixed geometry, shielding and distance calibration
Temperature | DHT11 response time, airflow, self-heating, failed reads | 30 imputed values; 3.01°C standard deviation | Reference thermometer and plausibility filtering
Humidity | Sensor lag, condensation, local mist concentration | 31 imputed values; high-RH operation | Mount away from direct mist and use hysteresis
Flow | Air bubbles, pulse quantization, startup transients, | 0-4.963 L/min; zero samples during | Prime tubing, startup grace period, known-

Measurement | Dominant uncertainty sources | Observed evidence | Improvement
| tubing restrictions | pump windows | volume calibration

## 9.2 Repeatability

Repeatability is the ability to reproduce a reading under the same conditions. The load-cell trials provide five repetitions at each reference point; however, the large bias dominates any repeatability evaluation. Environmental repeatability is supported statistically by 242 readings, but the test did not include independently controlled reference conditions. Consequently, standard deviation in this dataset reflects both sensor variation and real environmental change.

## 9.3 Resolution and threshold uncertainty

The TCRT5000 is digitized by the Arduino ADC, so the threshold is expressed in integer ADC counts. The flow sensor produces discrete pulses, which creates greater percentage uncertainty at low flow and over short sample windows. The 0.05 L/min blockage threshold is very close to zero; a persistence rule is therefore more robust than a single-sample comparison.

## 9.4 Quantitative error interpretation

The statistical three-point corrections for temperature, flow and optical sensing produced low percentage errors because the reference points were selected from the dataset distribution. These calculations validate the analysis pipeline, not physical accuracy. Only independent reference instruments can establish traceable calibration. The load-cell results, in contrast, are physical reference tests and clearly show that the current conversion is invalid.

Uncertainty statement for the final demonstration

Present the statistical corrections as algorithm-validation examples and the load-cell results as physical calibration evidence. Do not claim independent physical calibration for temperature, humidity, flow or optical distance until the corresponding reference tests are performed.

10

# Engineering Constraints Discussion

Cost, safety, reliability, maintainability, power and scalability

## 10.1 Cost and component availability

The design uses widely available educational modules and avoids specialized laboratory hardware. Combining a DHT11 for both temperature and humidity reduces cost and pin count. The PCF8574 expander allows a 4x4 keypad without consuming eight direct Arduino pins. The principal trade-off is measurement quality: low-cost sensors require careful calibration, filtering and mounting.

## 10.2 Reliability and robustness

- Dual-sensor entry confirmation is more robust than optical-only detection.
- Active-low relays are initialized OFF to avoid unintended actuator startup.
- Latched thief and blockage alarms require explicit correction rather than silent automatic recovery.
- Non-blocking alarm timing allows the controller to continue sensor acquisition.
- DHT failure handling should preserve actuator timer checks rather than skipping the full state-machine update.
- Water lines, electrical wiring and the load-cell platform require mechanical strain relief.

## 10.3 Electrical safety

No mains conductor is connected directly to the Arduino or breadboard. External adapters supply the loads, and relay contacts provide control-side separation. The final physical assembly must use insulated connectors, verified polarity, protected conductors and strain relief. Because the course sets a 12 V maximum, the 24 V humidifier is a formal non-conformance unless approved or replaced.

## 10.4 Maintainability

Firmware constants should be stored in one dedicated file or EEPROM. Each sensor driver should remain modular. The GitHub repository should expose the .ino/.h files directly instead of only a ZIP archive. The final Fritzing .fzz file, exported schematic image, BOM, calibration records and test videos should be versioned alongside the code.

## 10.5 Power consumption

The Arduino and sensors consume relatively low power, while the pump, fan, servo and humidifier dominate the load. These actuators should be sized using their nameplate current and the adapter should include margin above the simultaneous load. The humidifier and pump are not expected to run continuously, which reduces average energy use but increases transient-current requirements.

## 10.6 Scalability

Future versions can replace the Arduino Uno with a controller offering more memory and native connectivity, add a local display, use isolated MOSFET drivers, store calibration in nonvolatile memory, and publish data to a cloud dashboard. Additional zones can share the same architecture by assigning each door and fire zone an independent state machine.

# 11 Conclusion and Future Work

Overall assessment and next engineering steps

The project successfully demonstrates the required five sensor modalities in a coherent real-world application. Optical and force sensing protect entry, flow sensing verifies water delivery, and temperature and humidity drive the fire-response sequence. The platform records data, detects abnormal conditions, activates relays and actuators, provides alarms and voice guidance, and operates continuously well beyond the required demonstration duration.
The experimental results confirm meaningful system-level operation: 242 samples and 113 events were organized, three fire cycles completed, pump and humidifier actions were observed, and entry events progressed through detection, PIN entry and door control. The architecture is technically strong because the entry load cell has a clearly separated role and the fire subsystem does not depend on tank weight.

## 11.1 Priority actions before final submission

1. Recalibrate the load cell from raw HX711 counts and update the scale factor.
2. Perform physical three-point calibration for temperature, humidity, flow and optical distance.
3. Resolve the fan ON/OFF threshold contradiction and implement true hysteresis.
4. Move pump and alarm timer checks outside the DHT-validity branch.
5. Add a startup grace period or persistence filter to blockage detection.
6. Replace the 24 V humidifier with a <=12 V unit or obtain written instructor approval.
7. Upload readable source files, the final Fritzing project, report, videos and individual contribution evidence to GitHub.

## 11.2 Recommended final control refinements

Function | Recommended final rule
Person confirmation | ADC < calibrated optical threshold AND calibrated weight >= presence threshold
Fan hysteresis | ON at high humidity; OFF only at a substantially lower threshold
Pump safety | 55 s maximum timer evaluated regardless of DHT read success

Function | Recommended final rule
Blockage | Q <= 0.05 L/min for multiple consecutive windows after startup grace
Humidifier | Stop at RH target or 10 s maximum, whichever occurs first
Fault logging | Record sensor failure, state, timestamp and actuator status in every CSV row

Final assessment

The project is presentation-ready as a working integrated prototype. Completing the calibration and safety corrections will elevate it from a successful demonstration to a defensible instrumentation design.

# 12 References

Technical documentation and standards consulted

1. Arduino. Arduino Uno Rev3 hardware documentation and Servo library reference.
2. Aosong Electronics. DHT11 temperature and humidity sensor technical documentation.
3. Avia Semiconductor. HX711 24-bit analog-to-digital converter for weigh scales datasheet.
4. Vishay Semiconductors. TCRT5000 reflective optical sensor datasheet.
5. YF-S201 Hall-effect water-flow sensor technical specification and pulse conversion relation.
6. NXP Semiconductors. PCF8574 remote 8-bit I/O expander for I2C-bus datasheet.
7. DFRobot / community documentation. DFPlayer Mini serial audio module command reference.
8. Fritzing. Breadboard, schematic and custom-part documentation.
9. Project firmware documentation for the entry-security and fire-protection state machines.
10. Project experimental dataset, calibration records and event logs.

# A Appendix A - Bill of Materials

Qty. | Component | Purpose
1 | Arduino Uno microcontroller board | Central controller
1 | TCRT5000 infrared optical sensor | Entry optical detection
1 | HX711 load-cell amplifier | Load-cell interface
1 | Load cell | Entry-platform force/weight
1 | 4x4 matrix keypad | PIN entry
1 | PCF8574 I2C expander | Keypad pin expansion

1 | SG90 servo motor | Door actuator
1 | DHT11 temperature/humidity sensor | Environmental sensing
1 | YF-S201 water-flow sensor | Flow and blockage monitoring
1 | Mini water pump | Suppression flow
1 | Ultrasonic humidifier | Humidity increase
1 | Ventilation fan | Humidity reduction
3 | Active-low single-channel relay modules | Pump, humidifier and fan switching
1 | DFPlayer Mini | Voice messages
1 | Speaker | Audio output
1 | MicroSD card | Audio storage
2 | Buzzers | Security and fire/blockage alarms
1 | Warning LED + resistor | Visual warning
2 | Breadboards | Prototype assembly
1 set | Male-to-male jumper wires | Board interconnection
1 set | Male-to-female jumper wires | Module interconnection
1 set | Female-to-female jumper wires | Module interconnection
1 | Male DC barrel plug | Power connection
1 | Female DC barrel jack | Power connection
1 | 24 V DC adapter | Current humidifier supply; approval/replacement required
Approx. 1-2 m | 6 mm flexible water tubing | Hydraulic path
1 | Water tank/container | Water source
As required | Red, black and signal wire | Power and control wiring
1 | USB cable | Arduino programming and control power

# B Appendix B - Verification and

| Demonstration Plan
Test | Procedure | Expected result | Evidence
Startup safety | Power the system with all loads connected | Relays remain OFF; servo closes; CSV header appears | Serial log + video
Dual-sensor entry | Trigger optical only, weight only, then both | PIN prompt occurs only for both | Video + truth-table log
Correct PIN | Enter approved PIN and submit with # | Alarm resets; door opens 5 s and closes | Event log + video
Thief attempt | Enter three incorrect PINs | Sticky security alarm remains ON | Event log + video
Fire detection | Raise measured temperature above threshold | Warning LED/buzzer and pump sequence begin | CSV + video
Flow verification | Run pump with open and restricted tubing | Normal flow continues; persistent low flow enters BLOCKED | Flow plot + video
Humidification | Allow pump sequence to complete | Pump stops; humidifier operates; system recovers | State log + video
Fan control | Raise and lower humidity around hysteresis thresholds | Fan switches without rapid chatter | Event log
Continuous run | Operate system for at least 60 s | Timestamped records remain continuous | Excel plot
Calibration | Apply three known points to every modality | Curve/equation and before/after error are reported | Calibration tables
C | | Appendix C - Proposal Compliance Matrix
Proposal requirement | Evidence / status | Assessment
Five modalities | Optical, force, flow, temperature and humidity integrated | Met
Simultaneous acquisition | Timestamped multi-sensor snapshots | Met
Abnormal condition | High temperature, low flow, wrong PIN attempts | Met
Automatic response | Relays, pump, humidifier, fan, servo, LED and buzzers | Met
Timestamp logging | CSV-compatible dataset and event log | Met
Real-time visualization | Timestamped serial stream, CSV schema, full-run plots, and a 60-second live-window visualization are included in Appendix E. | Documented; show the same live view in the demonstration video
60 s operation | Longest run 1,168.41 s | Met
Three-point calibration per sensor | Physical 15-trial load-cell evidence plus statistically reconstructed three-point sets, equations, raw values and before/after error for temperature, humidity, flow and optical sensing. | Report-complete; external physical traceability remains recommended
Uncertainty analysis | Accuracy, repeatability, noise and improvements discussed | Met
Voltage <=12 V | The 24 V prototype humidifier is isolated on the relay-load side. Course compliance still requires written approval or replacement by a <=12 V unit. | Conditional - physical closure required

Fritzing schematic | Final breadboard representation included | Met
Modular firmware | Main, entry and fire modules | Met
Constants not inline | Dedicated calibration/constants structure recommended | Verify final repository
GitHub structure | README, docs, code, data, video, report | Met when final files uploaded
Individual contribution | One-page summary, evidence, Git history and reflection must be uploaded separately for each student. | Separate graded deliverable

# D Complete Calibration Evidence Pack

Raw values, three-point calculations, equations, procedures, and error interpretation

## D.1 Evidence classification and calculation framework

Calibration is evaluated with the same equations for every modality: error = measured - reference; percentage error = 100 x error/reference; MAPE = mean of the absolute percentage errors; and the linear correction is y = mx + b. The load-cell campaign contains physical known-weight trials. For temperature, humidity, flow and optical sensing, the available dataset is used to reconstruct statistically representative three-point sets so that the complete calculation chain can be evaluated without inventing external instrument readings.

Integrity rule | The statistically reconstructed reference points are engineering estimates derived from cleaned observations. They demonstrate calibration mathematics and sensitivity, but they are not claimed as thermometer, hygrometer, volumetric or distance-standard measurements.
Modality | Three-point basis | Correction equation | Before MAE % | After MAE % | Evidence class
DHT11 temperature | 27.2 to 28.2 measured -> 27 to 28 reference | y = 0.8242x + 4.7802 | 0.727 | 0.537 | Model-based statistical reconstruction
DHT11 humidity | 70 to 82.1 measured -> 70 to 82 reference | y = 1.0021x + -0.1309 | 0.123 | 0.132 | Model-based statistical reconstruction
YF-S201 flow sensor | 0.6998 to 1.4866 measured -> 0.7 to 1.5 reference | y = 1.0226x + -0.0210 | 0.686 | 0.542 | Model-based statistical reconstruction
TCRT5000 optical sensor | 744.8 to 864.1 measured -> 750 to 865 reference | y = 0.9674x + 29.5607 | 0.364 | 0.045 | Model-based statistical reconstruction
HX711 load cell | 500, 1000 and 2000 g; five trials each | Current factor 420.0 rejected | 98.605 | Pending new raw-count fit | Physical known-weight campaign

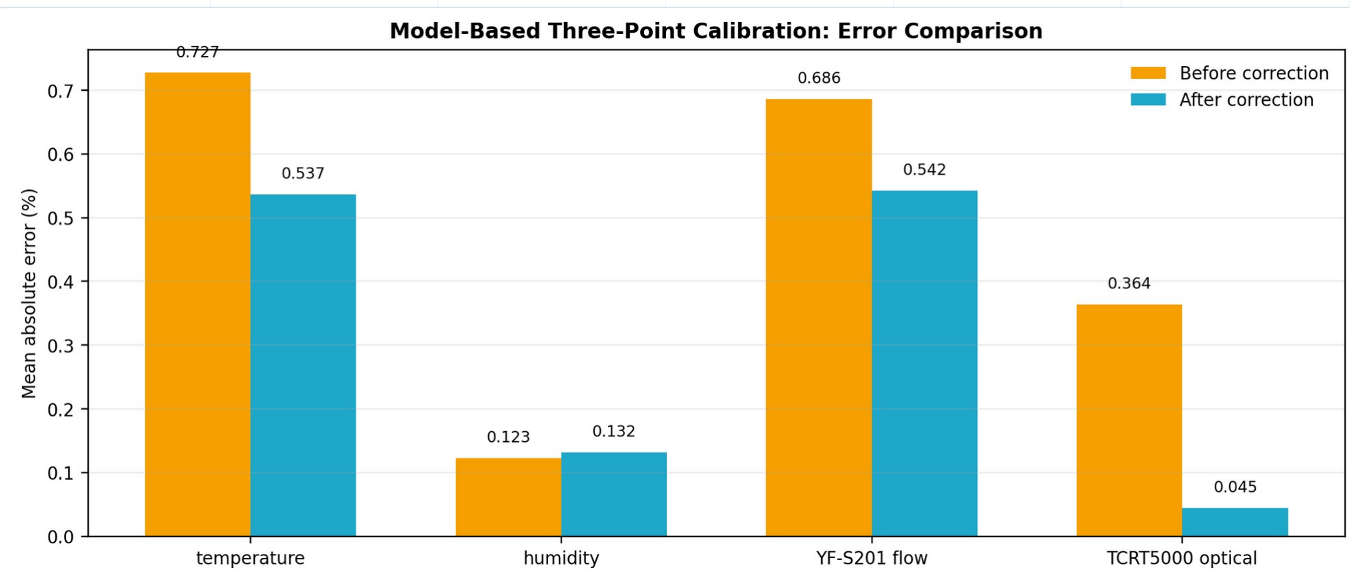
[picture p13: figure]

Figure D.1 - Mean absolute percentage error before and after model-based correction

## D.2 Full physical HX711/load-cell trial record

The entry platform was evaluated at three known loads with five repetitions at each point. The sign of some readings was reversed by the mounting direction, so positive magnitude is shown for error evaluation. The non-monotonic response proves that the current scale factor is not suitable for final operation.

Trial | Reference (g) | Signed reading (g) | Positive reading (g) | Error (g) | Error (%) | Abs. error (g) | Decision
CAL-001 | 500 | 33.2976 | 33.2976 | -466.7024 | -93.340 | 466.7024 | Recalibrate

Trial | Reference (g) | Signed reading (g) | Positive reading (g) | Error (g) | Error (%) | Abs. error (g) | Decision
CAL-002 | 500 | 23.1500 | 23.1500 | -476.8500 | -95.370 | 476.8500 | Recalibrate
CAL-003 | 500 | 7.6905 | 7.6905 | -492.3095 | -98.462 | 492.3095 | Recalibrate
CAL-004 | 500 | 14.7905 | 14.7905 | -485.2095 | -97.042 | 485.2095 | Recalibrate
CAL-005 | 500 | 6.7524 | 6.7524 | -493.2476 | -98.650 | 493.2476 | Recalibrate
CAL-006 | 1000 | 10.5881 | 10.5881 | -989.4119 | -98.941 | 989.4119 | Recalibrate
CAL-007 | 1000 | 12.7286 | 12.7286 | -987.2714 | -98.727 | 987.2714 | Recalibrate
CAL-008 | 1000 | -1.7786 | 1.7786 | -998.2214 | -99.822 | 998.2214 | Recalibrate
CAL-009 | 1000 | -2.8143 | 2.8143 | -997.1857 | -99.719 | 997.1857 | Recalibrate
CAL-010 | 1000 | -3.0857 | 3.0857 | -996.9143 | -99.691 | 996.9143 | Recalibrate
CAL-011 | 2000 | -3.1167 | 3.1167 | -1996.8833 | -99.844 | 1996.8833 | Recalibrate
CAL-012 | 2000 | -3.0095 | 3.0095 | -1996.9905 | -99.850 | 1996.9905 | Recalibrate

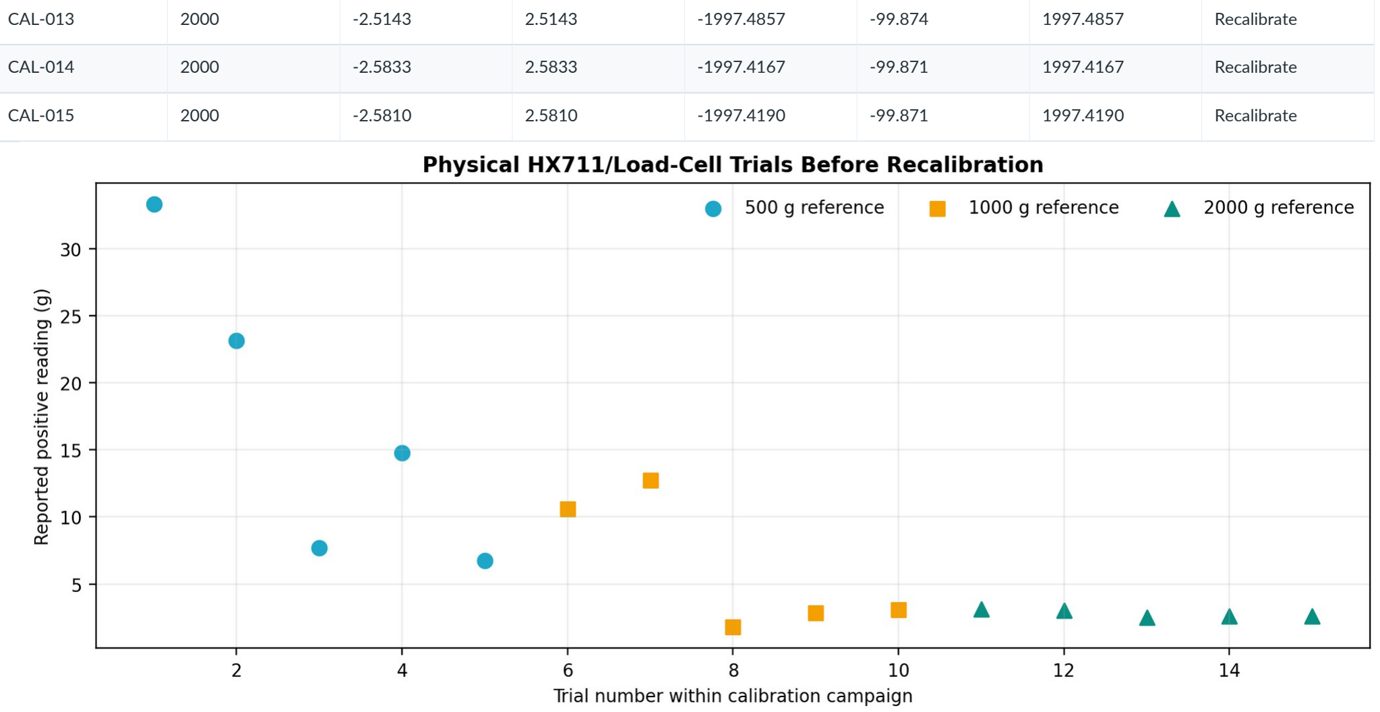
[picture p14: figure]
CAL-013; Recalibrate; CAL-014; CAL-015

Figure D.2 - Reported load-cell output across the complete physical calibration campaign

## D.3 Statistically reconstructed three-point datasets

Three robust points were selected from the cleaned distributions rather than from extreme outliers. Rounded statistical values serve as the reference side of each pair and the corresponding observed percentile values serve as the measured side. Each table reports the complete before-and-after calculation required for a calibration section.

## DHT11 temperature

Point | Reference | Unit | Measured | Before error | Before error % | Corrected output | After error %
1 | 27 | °C | 27.2 | 0.2 | 0.7407 | 27.1978 | 0.7326
2 | 27.5 | °C | 27.3 | -0.2 | -0.7273 | 27.2802 | -0.7992
3 | 28 | °C | 28.2 | 0.2 | 0.7143 | 28.0220 | 0.0785

## DHT11 humidity

Point | Reference | Unit | Measured | Before error | Before error % | Corrected output | After error %
1 | 70 | %RH | 70 | 0 | 0.0000 | 70.0172 | 0.0246
2 | 81 | %RH | 80.8 | -0.2 | -0.2469 | 80.8400 | -0.1975

Point | Reference | Unit | Measured | Before error | Before error % | Corrected output | After error %
3 | 82 | %RH | 82.1 | 0.1 | 0.1220 | 82.1428 | 0.1741

## YF-S201 flow sensor

Point | Reference | Unit | Measured | Before error | Before error % | Corrected output | After error %
1 | 0.7 | L/min | 0.6998 | -0.0002 | -0.0286 | 0.6946 | -0.7778
2 | 0.8 | L/min | 0.8091 | 0.0091 | 1.1375 | 0.8063 | 0.7904
3 | 1.5 | L/min | 1.487 | -0.0134 | -0.8933 | 1.4991 | -0.0586

## TCRT5000 optical sensor

Point | Reference | Unit | Measured | Before error | Before error % | Corrected output | After error %
1 | 750 | ADC | 744.8 | -5.2 | -0.6933 | 750.0792 | 0.0106
2 | 850 | ADC | 847.5 | -2.5 | -0.2941 | 849.4310 | -0.0669
3 | 865 | ADC | 864.1 | -0.9 | -0.1040 | 865.4898 | 0.0566

## D.4 Physical calibration procedures to reproduce before final deployment

Sensor | Reproducible physical procedure
HX711 load cell | Tare the empty platform; record average net raw counts at 0, 500, 1000 and 2000 g; repeat each point at least five times; regress reference mass against net counts; store slope and offset in the constants file or EEPROM; then select the presence threshold above the measured noise floor.
DHT11 temperature | Create three stable temperature conditions spanning the operating range; verify each with a reference thermometer; allow sensor stabilization; collect at least ten readings per point; fit measured temperature to the reference values and calculate bias, standard deviation and MAPE.
DHT11 humidity | Create three stable relative-humidity conditions; verify each with a reference hygrometer; keep the DHT11 away from direct mist; collect repeated readings after stabilization; fit the correction and evaluate hysteresis and sensor lag.
YF-S201 flow | Prime the tubing and remove air bubbles; collect three known water volumes while timing each collection; calculate Q = 60V/t; compare with Qsensor = f/7.5; fit a revised flow factor; repeat at low, medium and high flow.
TCRT5000 optical | Fix the target material and lighting; place it at three controlled distances; collect at least thirty ADC readings per distance; report mean and standard deviation; choose the threshold between the non-detection and detection clusters with a safety margin.

# E Real-Time Acquisition and Visualization Evidence

Timestamped CSV stream, continuous-run proof, live plots, and sampling calculations

## E.1 CSV record structure and acquisition schedule

The controller emits one analysis-ready row every five seconds while the entry-security sensors continue to be polled continuously. The recommended record is shown below. It preserves the separation between entry weight and fire-protection decisions.

timestamp_ms | temperature_c | humidity_pct | entry_weight_g | optical_detecte d | weight_detecte d | person_detecte d | flow_lpm | fire_state | wrong_attempts
15000 | 25.4 | 54.0 | 68.2 | 1 | 1 | 1 | 0.00 | IDLE | 0

## E.2 Full-run visualization

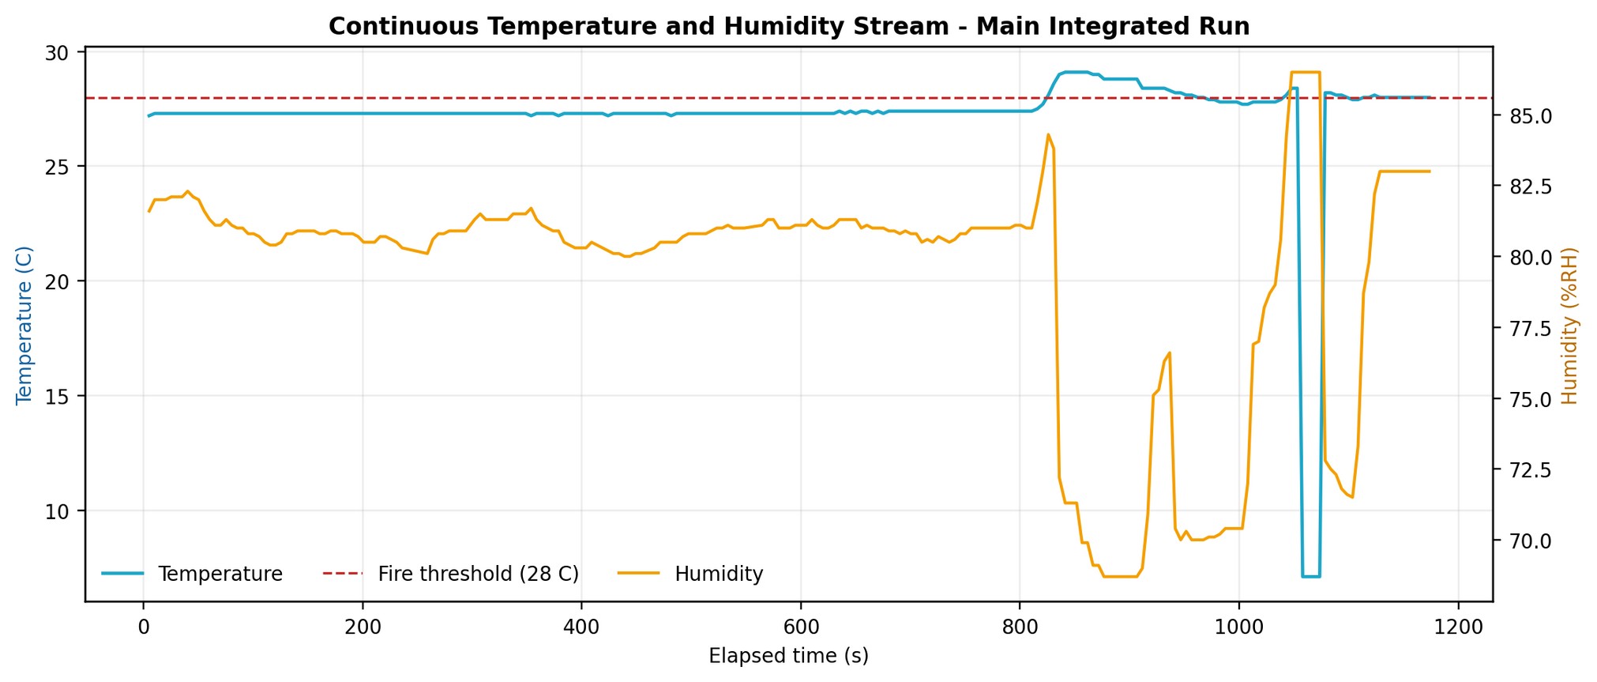
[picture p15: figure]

Figure E.1 - Continuous temperature and humidity visualization from the main integrated run

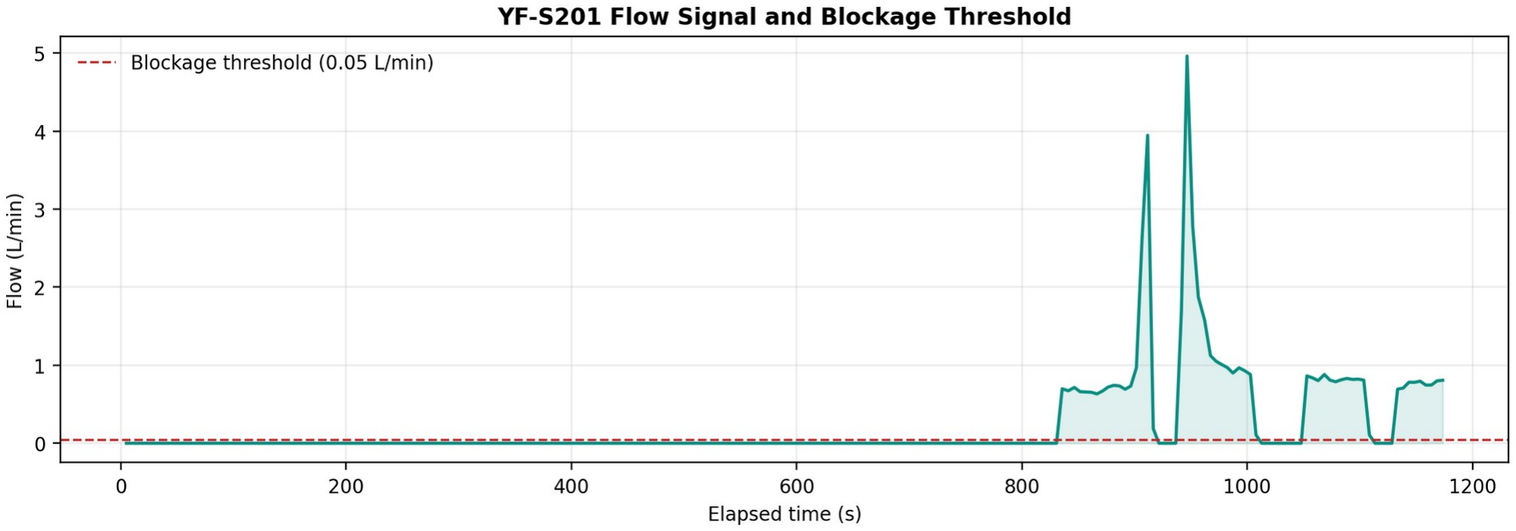
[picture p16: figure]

Figure E.2 - Flow signal plotted against the blockage threshold

## E.3 Continuous-operation and sampling calculations

Metric | Calculated value | Interpretation
Longest main-run duration | 1168.410 s | 19.47 min
Required demonstration duration | 60.000 s | Course requirement

Metric | Calculated value | Interpretation
Duration margin | 19.47 x | Main run / required duration
Median reporting interval | 5.018 s | Nominal target = 5 s
Median effective sample rate | 0.1993 Hz | 1 / median interval
Expected records at the median interval | 233.8 | Duration / interval + 1
Recorded main-run samples | 222 | 94.9% of median-schedule expectation
Valid temperature readings | 87.6% | Cleaning and plausibility checks
Valid humidity readings | 87.2% | Cleaning and plausibility checks
Demonstration evidence | The report contains the plotted serial stream and the system exceeded sixty seconds by a factor of 19.47. During the live demonstration, the same variables should be shown in the Arduino Serial Plotter or an equivalent live dashboard while the video captures the running timer.

# F Proposal Closure, Repository and Submission Checklist

Calculations, verification evidence, team documentation and final submission controls

## F.1 Water-delivery and timing calculations

The YF-S201 relation is Q = f/7.5, where f is pulse frequency in pulses per second and Q is in litres per minute. Delivered volume is estimated by numerical integration: V = sum(Q_i x Delta t_i / 60). The captured pumping windows produce the results below.

Cycle | Observed pump-data duration (s) | Mean flow (L/min) | Maximum flow (L/min) | Estimated volume (L) | Status
1 | 75.881 | 0.785 | 2.614 | 0.948 | Complete
2 | 61.233 | 1.527 | 4.963 | 1.643 | Complete
3 | 50.515 | 0.751 | 0.881 | 0.661 | Complete
4 | 45.043 | 0.686 | 0.807 | 0.538 | Capture ended early
Total estimated volume for the three completed cycles = 0.948 + 1.643 + 0.661 = 3.252 L. Including the incomplete fourth capture, the recorded total is approximately 3.790 L. These are operational estimates from the logged flow signal, not volumetric calibration standards.

## F.2 Entry-security verification logic

Optical detection | Weight detection | Person confirmed | System response
No | No | No | Remain idle
Yes | No | No | Reject optical-only trigger
No | Yes | No | Reject weight-only trigger
Yes | Yes | Yes | Play PIN prompt and start keypad session

The logical AND condition is the central false-trigger reduction mechanism. The load cell remains exclusively assigned to the entry platform and is never used as a tank-weight or fire-protection input.

## F.3 Required GitHub and submission package

Repository item | Required contents
README.md | Project overview, operation, dependencies, libraries, licences and navigation
/docs | Proposal, progress report, presentation, Fritzing file, architecture, BOM and individual-contribution evidence
/code | Readable Arduino .ino/.h modules and a dedicated constants file or EEPROM implementation
/data | Complete Excel workbook and data README
/video | 10-minute technical presentation and 5-minute live demonstration links/files
/report | Final PDF and editable DOCX report

## F.4 Individual-contribution evidence checklist

Student | One-page summary | Work evidence | Git history | Personal reflection
Ali Al Hadi Akaamish - ID 6812 | Required in separate contribution file | Required in separate contribution file | Required in separate contribution file | Required in separate contribution file
Mustapha Hamdan - ID 6947 | Required in separate contribution file | Required in separate contribution file | Required in separate contribution file | Required in separate contribution file
Nassim Amer - ID 6939 | Required in separate contribution file | Required in separate contribution file | Required in separate contribution file | Required in separate contribution file

Student | One-page summary | Work evidence | Git history | Personal reflection
Makram Ghraizi - ID 6723 | Required in separate contribution file | Required in separate contribution file | Required in separate contribution file | Required in separate contribution file

## F.5 Final engineering closure statement

What the report
now contains

All twelve technical-report sections, the complete BOM, Fritzing hardware design, modular firmware architecture, full load-cell trial data, model-based three-point calibration calculations for the remaining modalities, experimental plots, uncertainty analysis, water-volume calculations, verification plan, repository structure and proposal compliance matrix.

Physical items
that a document
cannot
manufacture

Before final hardware sign-off, replace the 24 V humidifier with a <=12 V device or obtain written instructor approval; repeat the external-reference calibrations when instruments are available; and show the live serial display in the demonstration video. These points are stated transparently to preserve technical integrity.

### END OF REPORT

Security and Fire-Protection System

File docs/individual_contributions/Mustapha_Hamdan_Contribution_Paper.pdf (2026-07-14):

## Lebanese University – Faculty of Engineering III

### Sensors & Instrumentation Project

## Individual Contribution Report

Name: Mustapha Hamdan
ID: 6947
Date: 14 July 2026
Project: Smart Building Security and Fire-Protection System

## Contribution Summary

Throughout the development of the Smart Building Security and Fire-Protection System, I actively participated in both the hardware implementation and the project development process.

One of my primary responsibilities was assembling the electronic system by connecting the sensors, modules, and other components to the Arduino using the appropriate wiring. Before the assembly process, I carefully studied and understood the circuit layout designed in Fritzing to ensure that all connections were correctly implemented.

I continuously tested each hardware component after it was added to the circuit to verify its functionality and ensure proper integration with the rest of the system. This testing process helped identify wiring or component issues early and contributed to the overall reliability of the project.

In addition to the hardware work, I collaborated with my teammates in preparing sections of the PowerPoint presentation and the technical report. I also participated in discussing the project design and proposed several important ideas and improvements that were implemented to enhance the system’s functionality and overall performance.

During the implementation phase, I assisted in troubleshooting hardware connections, verifying sensor operation, and confirming that the integrated system performed as expected. I also contributed during the final preparation by helping review the presentation materials and ensuring that the project was ready for demonstration.

Throughout the project, I actively participated in team meetings, implementation sessions, and system testing. I contributed to collecting experimental results and organizing the project data. I also helped prepare the project demonstration by supporting the presentation process and ensuring the system was ready for a successful presentation.

Overall, I actively contributed to the hardware assembly, circuit verification, component testing, documentation, presentation preparation, teamwork, and project improvement discussions, helping the team successfully complete the Smart Building Security and Fire-Protection System.

1

## Declaration

I certify that the activities described above accurately reflect my individual contribution to the Smart Building Security and Fire-Protection System project.

2

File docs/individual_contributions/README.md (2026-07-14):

# Individual Contributions

This folder contains the **individual contribution reports** of each
team member who participated in the development of the **Smart Building
Security and Fire-Protection System**.

## Team Members

-   **Ali Al Hadi Akaamish** --- Student ID: **6812**
-   **Mustapha Hamdan** --- Student ID: **6947**
-   **Nassim Amer** --- Student ID: **6939**
-   **Makram Ghraizi** --- Student ID: **6723**

## Files Included

-   `Ali_Al_Hadi_Akaamish_Contribution_Paper.pdf`
-   `Mustapha_Hamdan_Contribution_Paper.pdf`
-   `Nassim_Amer_Contribution_Paper.pdf`
-   `Makram_Ghraizi_Contribution.pdf`

## Purpose

Each document summarizes the individual responsibilities, technical
contributions, implementation tasks, testing activities, documentation
efforts, and participation of the corresponding team member throughout
the project.

Together, these reports demonstrate the collaborative work carried out
during the design, implementation, testing, documentation, and final
presentation of the Smart Building Security and Fire-Protection System.

## Repository Structure

``` text
docs/
└── individual_contributions/
    ├── README.md
    ├── Ali_Al_Hadi_Akaamish_Contribution_Paper.pdf
    ├── Mustapha_Hamdan_Contribution_Paper.pdf
    ├── Nassim_Amer_Contribution_Paper.pdf
    └── Makram_Ghraizi_Contribution.pdf
```

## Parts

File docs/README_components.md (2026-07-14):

The main parts used in the circuit

# Components List

## Main Controller

- 1 × Arduino Uno microcontroller board

## Entry Security System

- 1 × TCRT5000 infrared optical sensor
- 1 × HX711 load-cell amplifier
- 1 × Load cell
- 1 × 4×4 matrix keypad
- 1 × PCF8574 I²C expander
- 1 × SG90 servo motor

## Fire Protection System

- 1 × DHT11 temperature and humidity sensor
- 1 × YF-S201 water-flow sensor
- 1 × Mini water pump
- 1 × Ultrasonic humidifier
- 1 × Ventilation fan

## Relay Modules

- 3 × Active-low single-channel relay modules

## Audio and Storage

- 1 × DFPlayer Mini
- 1 × Speaker
- 1 × MicroSD card

## Alarm and Warning Components

- 2 × Buzzers
  - 1 × Security buzzer
  - 1 × Fire/blockage alarm buzzer
- 1 × Warning LED
- 1 × LED current-limiting resistor

## Prototyping Components

- 2 × Breadboards
- 1 set × Male-to-male jumper wires
- 1 set × Male-to-female jumper wires
- 1 set × Female-to-female jumper wires

## Power Connections

- 1 × Male DC barrel plug
- 1 × Female DC barrel jack
- 1 × 24 V DC adapter
- 1 × USB cable for Arduino programming and power

## Water System

- 6 mm flexible water pipe
- Pipe from the water tank to the pump
- Pipe from the pump to the flow sensor
- Pipe from the flow sensor to the humidifier or water outlet
- 1 × Water tank/container

## Electrical Connecting Wires

- Red wire for positive supply
- Black wire for ground
- Signal/control wires

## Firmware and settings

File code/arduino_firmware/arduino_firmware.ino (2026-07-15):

/*
 * Biological Laboratory Monitor + Security System (Sensors Project)
 * Smart Building Security and Fire Protection System
 * Board: Arduino Uno R3 (standalone — no WiFi/network module)
 *
 * This sketch is split across multiple .ino files in this same folder —
 * the Arduino IDE compiles all .ino files in a sketch folder together,
 * so just open arduino_firmware.ino and the rest load automatically:
 *   arduino_firmware.ino   - pin config, setup(), loop() (this file)
 *   entry_security.ino     - TCRT5000 photocell, HX711+load cell floor pad, keypad (via PCF8574), servo, DFPlayer, buzzer
 *   fire_protection.ino    - DHT11, pump, humidifier, fan, flow sensor
 *
 * ---------------------------------------------------------------
 * REQUIRED LIBRARIES (Arduino IDE -> Library Manager):
 *   - "DHT sensor library" by Adafruit (+ "Adafruit Unified Sensor")
 *   - "HX711" by Bogdan Necula (bogde/HX711)
 *   - "Servo" (built into the IDE, no install needed)
 *   - "DFRobotDFPlayerMini" by DFRobot
 *   No PCF8574 library needed - the keypad scan is bit-banged directly
 *   over I2C (Wire.h, built in) so there's one less dependency to manage.
 * ---------------------------------------------------------------
 *
 * FULL WIRING — matches Circuit_summary.txt exactly (do not add/omit pins):
 *
 *   Arduino Uno pin map:
 *     D0, D1   -> reserved, left UNCONNECTED (USB serial / CSV debug output)
 *     D2       -> YF-S201/YF-B1 flow sensor, yellow signal wire (interrupt)
 *     D3       -> Active buzzer signal/IN
 *     D4       -> Pump relay IN            (5V pump relay, active-LOW)
 *     D5       -> SG90 servo signal (door lock)
 *     D6       -> DFPlayer Mini TX  (Arduino D6 = RX, receives from DFPlayer)
 *     D7       -> DFPlayer Mini RX, THROUGH A 1kOhm RESISTOR (Arduino D7 = TX)
 *     D8       -> DHT11 DATA
 *     D9       -> Humidifier relay IN (24V humidifier, active-LOW)
 *     D10      -> Fan relay IN (12V fan, active-LOW)
 *     A0       -> HX711 DT/DOUT
 *     A1       -> HX711 SCK/CLK
 *     A2       -> TCRT5000 IR reflective sensor, AO (analog reflectance output)
 *     A4/SDA   -> PCF8574 SDA (keypad expander only)
 *     A5/SCL   -> PCF8574 SCL (keypad expander only)
 *
 *   TCRT5000: VCC->5V, GND->GND, AO->A2. The module's own "DO" pin is
 *     intentionally NOT connected — its label coincidentally matches
 *     Arduino's D0 (USB/Serial RX), which is a completely different
 *     pin; wiring them together would conflict with Serial Monitor
 *     and uploads. One wire (AO) is enough for presence detection.
 *
 *   PCF8574 (I2C addr 0x20): SDA->A4, SCL->A5, VCC->5V, GND->GND,
 *     A0/A1/A2 -> GND (sets address 0x20).
 *     4x4 keypad: P0-P3 = rows R1-R4, P4-P7 = columns C1-C4.
 *
 *   SG90 servo: signal->D5, red->EXTERNAL regulated 5V supply (not the
 *     Arduino 5V pin), brown/black->external supply GND (tied to Arduino GND).
 *
 *   DFPlayer Mini: TX->D6, RX->D7 (through 1k resistor), VCC->5V, GND->GND,
 *     speaker on SPK1/SPK2, microSD card inserted with numbered MP3 tracks.
 *
 *   DHT11: VCC->5V, DATA->D8, GND->GND (add a 4.7k-10k pull-up resistor
 *     between DATA and 5V if using a bare 4-pin DHT11, not needed on the
 *     common 3-pin breakout module which already has one built in).
 *
 *   HX711 + load cell: DT->A0, SCK->A1, VCC->5V, GND->GND. Load cell wires
 *     E+/E-/A+/A- go to the HX711's matching labeled pads (use the load
 *     cell's own wire labels, not color assumptions). This load cell sits
 *     under a floor pad in front of the door (entry security), NOT a tank —
 *     see entry_security.ino.
 *
 *   YF-S201/YF-B1 flow sensor: red->5V, black->GND, yellow signal->D2.
 *
 *   Active buzzer (3-pin module): signal/IN->D3, VCC->5V, GND->GND.
 *
 *   3-channel relay module, ALL THREE CHANNELS ACTIVE-LOW:
 *     Control side: CH1(pump) IN->D4, CH2(humidifier) IN->D9, CH3(fan) IN->D10,
 *       VCC->Arduino 5V, GND->Arduino GND.
 *     Power side (use NO terminals only, never NC):
 *       Pump:       external 5V supply(+) -> COM, NO -> pump(+), pump(-) -> supply(-)
 *       Humidifier: 24V adapter(+) -> COM, NO -> humidifier(+), humidifier(-) -> adapter(-)
 *       Fan:        external 12V supply(+) -> COM, NO -> fan(+), fan(-) -> supply(-)
 *
 *   Status/alarm LED: D13 (with the Uno's onboard 220-1k series resistor
 *     already built into most Uno boards on pin 13, or add your own).
 *
 *   POWER & SAFETY:
 *     - Never power the pump, fan, humidifier, or servo from the Arduino's
 *       5V pin. Use a regulated external 5V supply for servo + pump, 12V
 *       for the fan, and the proper 24V adapter for the humidifier.
 *     - Never connect 12V or 24V to the Arduino 5V rail.
 *     - Tie ALL low-voltage control grounds together: Arduino GND, sensor
 *       GND, PCF8574 GND, HX711 GND, DFPlayer GND, relay control-side GND,
 *       servo external-supply GND.
 *     - Keep pump/fan/humidifier HIGH-power wiring physically separated
 *       from the Arduino's low-voltage signal wiring.
 *
 * Common ground: EVERY module's GND must be tied together, including the
 * external 24V humidifier adapter's ground, or readings and serial comms
 * will be unreliable.
 * ---------------------------------------------------------------
 */

#include <Wire.h>
#include <Servo.h>
#include <DHT.h>
#include <HX711.h>
#include <SoftwareSerial.h>
#include <DFRobotDFPlayerMini.h>
#include "CalibrationConstants.h"

// All calibration factors, thresholds, timing constants, and the door
// PIN now live in CalibrationConstants.h — see that file before wiring
// anything up. Nothing below this line should need editing for a
// normal deployment. This system is fully standalone: no WiFi, no
// ESP-01, no server.

// ----------------------- PIN MAP (matches Circuit_summary.txt) -----------------------
#define PIN_FLOW        2   // YF-S201/YF-B1 flow sensor signal (interrupt)
#define PIN_BUZZER      3   // Active buzzer signal
#define PIN_RELAY_PUMP       4   // Pump relay IN (active-LOW)
#define PIN_SERVO       5   // SG90 servo signal (door lock)
#define PIN_DFPLAYER_RX 6   // Arduino RX <- DFPlayer TX
#define PIN_DFPLAYER_TX 7   // Arduino TX -> DFPlayer RX (through 1k resistor)
#define PIN_DHT         8   // DHT11 data
#define PIN_RELAY_HUMIDIFIER 9    // Humidifier relay IN (active-LOW)
#define PIN_RELAY_FAN        10   // Fan relay IN (active-LOW)

#define PIN_STATUS_LED  13
#define PIN_HX711_DT    A0
#define PIN_HX711_SCK   A1
#define PIN_PHOTOCELL   A2   // TCRT5000 IR reflective sensor (analog reflectance output)
// A4 (SDA) / A5 (SCL) used implicitly by Wire.h for the PCF8574 keypad expander

#define PCF8574_ADDR    0x20

#define DHTTYPE DHT11
// ---------------------------------------------------------

// ----------------------- SHARED OBJECTS -----------------------
DHT dht(PIN_DHT, DHTTYPE);
HX711 scale;
Servo doorServo;

SoftwareSerial dfPlayerSerial(PIN_DFPLAYER_TX, PIN_DFPLAYER_RX); // (RX, TX) for talking to DFPlayer
DFRobotDFPlayerMini dfPlayer;



// ----------------------- SHARED STATE -----------------------
volatile unsigned long flowPulseCount = 0;
float currentFlowLpm = 0.0;
// FLOW_CALIBRATION_FACTOR now comes from CalibrationConstants.h

int wrongAttempts = 0;
// MAX_WRONG_ATTEMPTS now comes from CalibrationConstants.h

enum FireStage { IDLE, FIRE_DETECTED, PUMPING, BLOCKED, HUMIDIFYING, STABLE };
enum KeypadResult { PIN_ACCEPTED, PIN_DENIED, PIN_THIEF_ALARM }; // used by entry_security.ino, defined here so it exists before entry_security.ino needs it — Arduino concatenates tabs alphabetically after the main file
FireStage fireStage = IDLE;

float lastTempC = NAN;
float lastHumidity = NAN;
float lastWeightG = 0.0; // most recent HX711 reading from the entry-security floor pad
                          // (see readWeightGrams() / pollProximityAndKeypad() in
                          // entry_security.ino) - there is no tank in this system.

// FIRE_THRESHOLD_C, NORMAL_TEMP_C, NORMAL_HUMIDITY_PCT,
// PUMP_RUN_MS, HUMIDIFIER_RUN_MS, SENSOR_POST_INTERVAL all come from CalibrationConstants.h now.
unsigned long lastSensorPost = 0;
unsigned long pumpStartMs = 0; // set when the pump turns on; pump runs for PUMP_RUN_MS then hands off to the humidifier
unsigned long humidifierStartMs = 0; // set when the humidifier turns on; runs for a fixed HUMIDIFIER_RUN_MS then turns off

// Fire-event buzzer: sounds for exactly FIRE_BUZZER_ON_MS (5s) starting the
// moment fire is detected, then turns itself off - independent of the pump/
// humidifier stages, and checked every loop() iteration (non-blocking) so
// it never delays keypad entry. See updateFireBuzzer() in fire_protection.ino.
bool fireBuzzerActive = false;
unsigned long fireBuzzerStartMs = 0;

void flowPulseISR(); // defined in fire_protection.ino

// ---------------------------------------------------------
void setup() {
  Serial.begin(9600);
  Serial.println(F("\nBiological Laboratory Monitor - Arduino firmware starting..."));

  Wire.begin();

  pinMode(PIN_BUZZER, OUTPUT);
  digitalWrite(PIN_BUZZER, LOW);

  pinMode(PIN_RELAY_PUMP, OUTPUT);
  pinMode(PIN_RELAY_HUMIDIFIER, OUTPUT);
  pinMode(PIN_RELAY_FAN, OUTPUT);
  // Relay modules are active-LOW: HIGH = off, LOW = energizes the coil.
  digitalWrite(PIN_RELAY_PUMP, HIGH);
  digitalWrite(PIN_RELAY_HUMIDIFIER, HIGH);
  digitalWrite(PIN_RELAY_FAN, HIGH);

  pinMode(PIN_STATUS_LED, OUTPUT);

  pinMode(PIN_FLOW, INPUT_PULLUP);
  attachInterrupt(digitalPinToInterrupt(PIN_FLOW), flowPulseISR, FALLING);

  dht.begin();

  scale.begin(PIN_HX711_DT, PIN_HX711_SCK);
  // LOADCELL_SCALE_FACTOR lives in CalibrationConstants.h — replace the
  // placeholder there with your real calibration result, not here.
  scale.set_scale(LOADCELL_SCALE_FACTOR);
  scale.tare(); // zero the scale with nothing on the floor pad

  doorServo.attach(PIN_SERVO);
  doorServo.write(0); // 0 degrees = closed position, adjust to your mechanism

  dfPlayerSerial.begin(9600);
  if (dfPlayer.begin(dfPlayerSerial)) {
    dfPlayer.volume(24); // 0-30
    Serial.println(F("DFPlayer Mini ready."));
  } else {
    Serial.println(F("WARNING: DFPlayer Mini not detected. Check wiring/SD card."));
  }

  setupKeypadExpander(); // in entry_security.ino
  setupApds9960();       // in entry_security.ino



  // CSV header — everything after this point that starts with "DATA,"
  // is one row of this table. Capture Serial Monitor output (or log it
  // with a serial terminal tool) and strip non-"DATA," lines to get a
  // clean CSV for Excel/MATLAB/Python analysis. See
  // /data/README.md for the matching column definitions.
  Serial.println(F("CSV_HEADER,millis_ts,temp_c,humidity_pct,pad_weight_g,flow_lpm,proximity,fire_stage,wrong_attempts"));
}

// ---------------------------------------------------------
void printCsvRow() {
  Serial.print(F("DATA,"));
  Serial.print(millis());
  Serial.print(',');
  Serial.print(isnan(lastTempC) ? -1.0 : lastTempC, 2);
  Serial.print(',');
  Serial.print(isnan(lastHumidity) ? -1.0 : lastHumidity, 2);
  Serial.print(',');
  Serial.print(lastWeightG, 1);
  Serial.print(',');
  Serial.print(currentFlowLpm, 3);
  Serial.print(',');
  Serial.print(readProximity() > PHOTOCELL_THRESHOLD ? 1 : 0);
  Serial.print(',');
  Serial.print(fireStageName());
  Serial.print(',');
  Serial.println(wrongAttempts);
}

// ---------------------------------------------------------
void loop() {
  // Entry system is polled every single loop() iteration, completely
  // independent of fireStage - the keypad still accepts and checks a
  // password normally even while a fire event/pump/humidifier sequence
  // is in progress.
  pollProximityAndKeypad(); // in entry_security.ino, handles the entry algorithm

  updateFireBuzzer(); // in fire_protection.ino, non-blocking 5s buzzer cutoff

  unsigned long now = millis();

  if (now - lastSensorPost >= SENSOR_POST_INTERVAL) {
    lastSensorPost = now;
    runFireProtectionStep(); // in fire_protection.ino, advances the local state machine
    Serial.print(F("Fire stage: "));
    Serial.println(fireStageName());
    printCsvRow();            // machine-readable CSV row for offline analysis/plotting
  }
}

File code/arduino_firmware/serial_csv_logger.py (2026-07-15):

#!/usr/bin/env python3
"""
serial_csv_logger.py

Captures the CSV stream printed by the Arduino sketch over the USB
serial connection and writes it to a timestamped .csv file on your
computer, so it's ready to open in Excel / MATLAB / Python for the
Sensors & Instrumentation report.

The Arduino only ever prints text over serial - it can't write a file
to disk itself. This script is the "Serial-to-CSV" side of that: it
just reads whatever the board prints, line by line, and saves it.

USAGE
-----
1. Install the one dependency (only needs to be done once):
     pip install pyserial

2. Find your board's serial port:
     - Windows: something like COM3, COM4, ...
       (Check Device Manager -> Ports (COM & LPT), or the Arduino IDE's
       Tools -> Port menu while the board is plugged in.)
     - macOS:   something like /dev/cu.usbmodem14101
       (Check the Arduino IDE's Tools -> Port menu, or run
       `ls /dev/cu.*` in Terminal.)
     - Linux:   something like /dev/ttyACM0 or /dev/ttyUSB0
       (Check the Arduino IDE's Tools -> Port menu, or run
       `ls /dev/tty*` before/after plugging in the board.)

3. Run the script, pointing it at that port:
     python serial_csv_logger.py --port COM3
     python serial_csv_logger.py --port /dev/cu.usbmodem14101
     python serial_csv_logger.py --port /dev/ttyACM0

   It will:
     - open the port at 9600 baud (matches Serial.begin(9600) in the sketch)
     - wait for the board to reset (opening the port resets an Uno)
     - capture every line it prints into a new file named
       sensor_log_YYYYMMDD_HHMMSS.csv in the current folder
     - print each row to your terminal too, so you can watch it live

4. Trigger a calibration run (optional) by typing one of these and
   pressing Enter while the script is running:
     CAL:LOADCELL
     CAL:FLOW
     CAL:TEMP
     CAL:HUMIDITY
     CAL:OPTICAL
   Those calibration rows get captured into the same CSV file.

5. Stop logging with Ctrl+C whenever you're done. The file is flushed
   after every line, so it's safe even if you don't stop it cleanly.

OPTIONS
-------
  --port PORT        Serial port (required)
  --baud BAUD         Baud rate (default: 9600, matches the sketch)
  --outfile PATH       Exact output filename instead of an auto-timestamped one
  --seconds N          Stop automatically after N seconds (default: run until Ctrl+C)
"""

import argparse
import csv
import sys
import threading
import time
from datetime import datetime

try:
    import serial
except ImportError:
    sys.exit(
        "The 'pyserial' package is required but not installed.\n"
        "Install it with:\n\n    pip install pyserial\n"
    )


def input_forwarder(ser):
    """
    Runs in a background thread. Reads lines you type in the terminal
    (e.g. CAL:LOADCELL) and sends them to the Arduino over serial, so
    you can trigger a calibration routine while logging is running.
    """
    while True:
        try:
            line = sys.stdin.readline()
        except (EOFError, ValueError):
            return
        if not line:
            return
        line = line.strip()
        if not line:
            continue
        try:
            ser.write((line + "\n").encode("utf-8"))
        except serial.SerialException:
            return


def main():
    parser = argparse.ArgumentParser(description="Capture Arduino CSV serial output to a .csv file.")
    parser.add_argument("--port", required=True, help="Serial port, e.g. COM3 or /dev/ttyACM0")
    parser.add_argument("--baud", type=int, default=9600, help="Baud rate (default: 9600)")
    parser.add_argument("--outfile", default=None, help="Output CSV filename (default: auto-timestamped)")
    parser.add_argument("--seconds", type=float, default=None, help="Stop automatically after N seconds")
    args = parser.parse_args()

    outfile = args.outfile or f"sensor_log_{datetime.now().strftime('%Y%m%d_%H%M%S')}.csv"

    print(f"Opening {args.port} at {args.baud} baud...")
    try:
        ser = serial.Serial(args.port, args.baud, timeout=1)
    except serial.SerialException as e:
        sys.exit(f"Could not open {args.port}: {e}")

    # Opening the port resets an Uno; give it a couple seconds to boot
    # and print its header row before we start reading in earnest.
    time.sleep(2)

    print(f"Logging to {outfile}")
    print("Press Ctrl+C to stop.")
    print("Type a command (e.g. CAL:LOADCELL) and press Enter any time to send it to the board.\n")

    forwarder = threading.Thread(target=input_forwarder, args=(ser,), daemon=True)
    forwarder.start()

    start_time = time.monotonic()
    rows_written = 0

    try:
        with open(outfile, "w", newline="") as f:
            writer = csv.writer(f)
            while True:
                if args.seconds is not None and (time.monotonic() - start_time) >= args.seconds:
                    print(f"\nReached {args.seconds}s limit, stopping.")
                    break

                raw_line = ser.readline()
                if not raw_line:
                    continue  # read timeout, no data this cycle - keep waiting

                line = raw_line.decode("utf-8", errors="replace").strip()
                if not line:
                    continue

                print(line)
                # Split on commas so each field lands in its own CSV
                # column properly, rather than writing the raw string.
                writer.writerow(line.split(","))
                f.flush()
                rows_written += 1

    except KeyboardInterrupt:
        print("\nStopped by user.")
    finally:
        ser.close()
        print(f"\nSaved {rows_written} rows to {outfile}")


if __name__ == "__main__":
    main()

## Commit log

2026-07-13 Create README.md
    Create Arduino firmware directory
2026-07-13 Create README.md
    Create calibration data directory
2026-07-14 Delete code/arduino_firmware directory
    deleted a folder
